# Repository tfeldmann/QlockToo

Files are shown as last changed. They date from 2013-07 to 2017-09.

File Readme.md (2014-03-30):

QlockToo
========
In this repository you find the software, firmware and hardware design for the
"QlockToo", an open-source remake of the QLOCKTWO by BIEGERT & FUNK.

It is built by four Westfälische Hochschule master mechatronics students.

Software
--------
The QlockToo Software Suite is written in PySide.

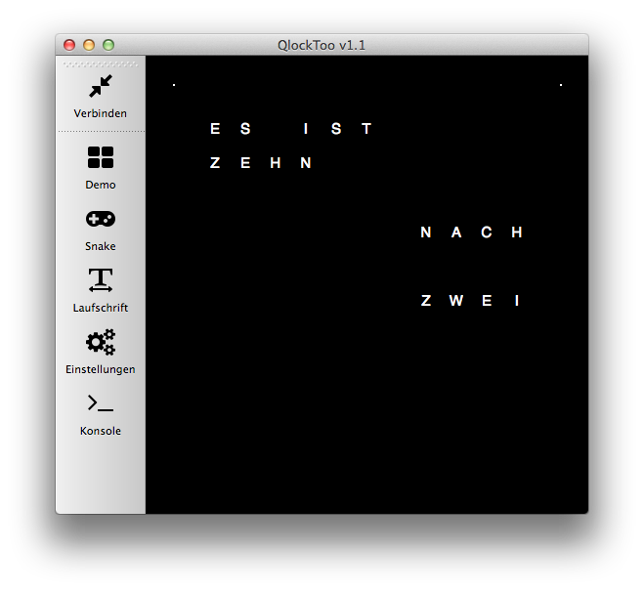
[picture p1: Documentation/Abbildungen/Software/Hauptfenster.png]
Software


Firmware
--------
We use an Arduino Micro as the central microcontroller.

License
-------
MIT-License - please refer to the License.txt in this repository.

Api
---
    @(get|set)brightness
        min                     int 0 - 255
        max                     int 0 - 255

    @(get|set)_nightmode
        brightness               int 0 - 255
        hour_start               int 0 - 23
        hour_end                 int 0 - 23
        minute_start             int 0 - 59
        minute_end               int 0 - 59

    @(get|set)kioskmode
        duration_words          int, minutes
        duration_seconds        int, minutes
        duration_temperature    int, minutes

    # matrix stream
    @m
        row     int 0 - 10
        values  bytearray

Errors
------

    !001 Unknown Command
    !002 Incorrect parameters

Authors
-------
- Thomas Feldmann
- Marlene Feldmann
- Manuel Fehmer
- Carsten Hußmann

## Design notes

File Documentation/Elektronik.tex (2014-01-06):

% !TEX root = QlockToo.tex
\begin{multicols}{2}
\section{Elektronik}
\label{sec:Elektronik}
Während sich Konstruktion und Basisfunktionen der Worduhr sehr eng am Original orientieren, ist die Umsetzung in der Elektronik komplett selbst entwickelt.

\textbf{LED-Matrix} Die LED-Matrix mit 10~x~11 Pixel wird von einem Mikrocontroller angesteuert. Dies geschieht zeilenweise im Multiplexing-Verfahren. Hierbei wird die erste Zeile von einem Transistor mit Spannung versorgt. Die 11 Pixel der Zeile werden über einen LED-Treiber simultan angesteuert. Nach einer Millisekunde wird die Zeile ausgeschaltet, es werden neue Daten in den LED-Treiber geschrieben und die nächste Zeile wird eingeschaltet.

\textbf{Arduino Micro} Als Mikrocontroller wird ein Arduino Micro Board mit dem Atmel Atmega 32U4 Controller verwendet. Der Einsatz eines Arduino Boards vereinfacht die Umsetzung einer seriellen Schnittstelle und verringert durch das bereits vielfach genutzte Board die Fehlerquellen im Layout. Durch die kleine Bauform und die sich aus den Features ergebenden Anforderungen (serielle Kommunikation, $I^{2}C$-Bus, externer Interrupt, 4x Digital Input, 2x Analogeingang und 10x Digital Output) fiel die Auswahl auf den Arduino Micro.

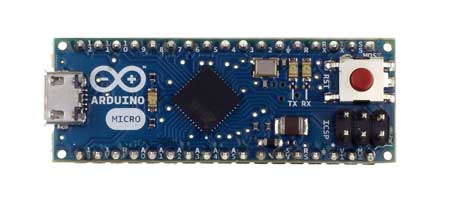
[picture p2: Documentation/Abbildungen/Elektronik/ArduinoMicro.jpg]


\textbf{LED-Treiber} Der TLC59116 LED-Treiber von Texas Instruments hat 16 PWM-Ausgänge mit 8Bit Auflösung - 256 Helligkeitsstufen - und eine Stromregelung, die es ermöglicht auf Vorwiderstände an den LED zu verzichten. Der IC wird über $I^{2}C$ angesteuert. Die Adresse kann hardwareseitig in den letzten 4Bit eingestellt werden und ist auf der Platine hart mit 0b1100 000[R/W] adressiert. Der LED-Treiber ist in der SMD TSSOP-28 Bauform.

\textbf{Transistoren} Die Zeilen werden mit IRF7416 P-FET-Transistoren geschaltet und mit $5V$ versorgt. Die Transistoren werden mit einem Pull-Up Widerstand am Gate beschaltet und mit einem invertierten Signal angesteuert (4~-~13). Die Transistoren haben S0-8 Gehäusebauform.

\textbf{Taster} Die vier Kurzhubtaster an der rechten Rahmenseite befinden sich auf einer eigenen Platine mit Verbindungskabel. Zur Entprellung befindet sich kurz vor den vier IO-Pins (A2~-~A5) des Controllers ein RC-Glied.

{
\centering
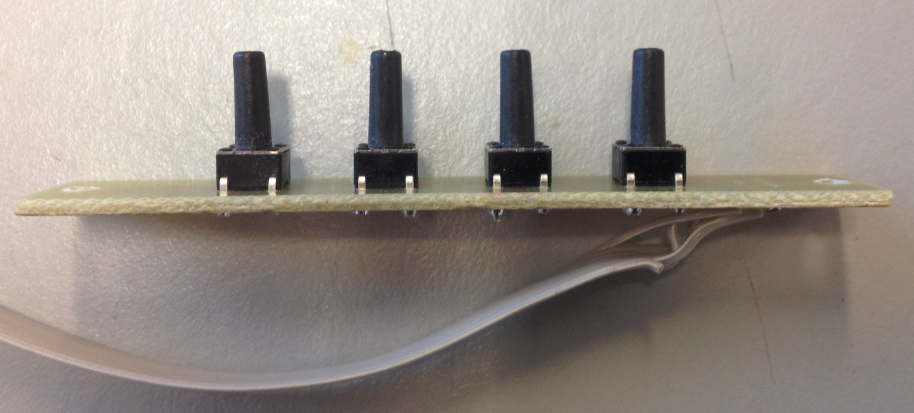
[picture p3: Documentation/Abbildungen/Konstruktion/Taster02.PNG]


}

{
\centering


}

Die vier Kurzhubtaster an der rechten Rahmenseite befinden sich auf einer eigenen Platine mit Verbindungskabel. Zur Entprellung befindet sich kurz vor den vier IO-Pins (A2~-~A5) des Controllers ein RC-Glied.

\textbf{Sensoren} Als Helligkeitssensor wird ein LDR und als Temperatursensor ein NTC verwendet, in beiden Fällen über Steckverbindung verbunden und einem Trimmpoti als Spannungsteiler an einem Analogeingang (A0~-~A1) des Mikrocontrollers. Der Helligkeitssensor befindet sich mittig oberhalb der Buchstabenmatrix hinter einem Loch in der Folie. Der Temperatursensor befindet sich seitlich am Rahmen um den Einfluss der möglichen Erwärmung der Elektronik auf den Sensor zu verringern. \newline

{
\centering
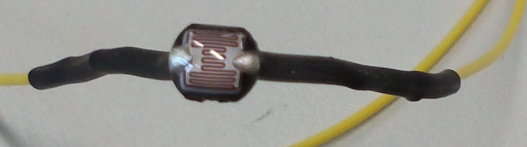
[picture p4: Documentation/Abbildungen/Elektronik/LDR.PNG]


}

{
\centering
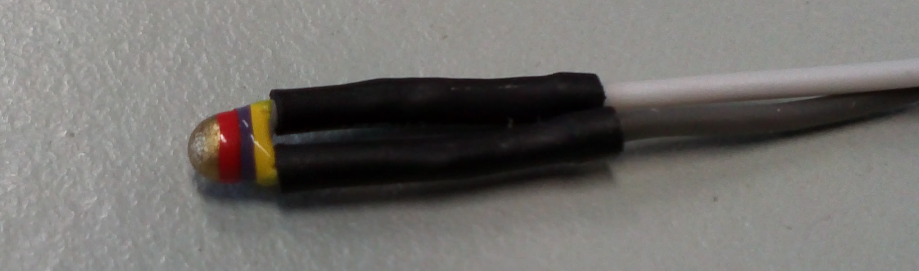
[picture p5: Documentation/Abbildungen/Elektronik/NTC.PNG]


}

\textbf{DCF77} Das DCF77-Modul empfängt das Mitteleuropäische Zeitsignal und verstärkt es. Um das Signal problemlos zu Empfangen wird hier ein interruptfähiger Eingang des Mikrocontrollers (1) verwendet. Durch regelmäßigen Empfang des DCF77 Zeitsignals ist die Genauigkeit des verbauten Quarz hinreichend genau.\newline

\textbf{Spannungsversorgung} Die Spannungsversorgung ist auf den Betrieb mit einem Gleichspannungsnetzteil (7~-~18$V$) ausgelegt und in die zwei Bereiche Elektronik und LED aufgeteilt. Der Bereich Elektronik wird von dem Spannungsregler auf dem Arduino Board versorgt. Die LEDs haben einen eigenen LM7805 Spannungsregler mit 1,5A Ausgangsstrom. An der Hohlsteckerbuchse am Rahmen kann alternativ ein Brückengleichrichter eingelötet werden, dieser verhindert die Verpolung des Netzteils und reduziert den Spannungsfall an den Spannungsreglern. Im Normalbetrieb benötigt die QlockToo 0,1A und 0,23A bei voller Helligkeit aller LED.

\textbf{Platinenlayout} Das Platinenlayout wurde mit dem PCB Design Tool CADSoft Eagle erstellt. Die Leiterbahnen des Top-Layers sind in Rot dargestellt und die Leiterbahnen, sowie die Massefläche, des Bottom-Layers sind in Blau dargestellt. Im oberen Bereich des Top-Layers befinden sich die 10 P-FET Transistoren mit  Pull-Up Widerständen. Rechts befindet sich der LED-Treiber mit dem Widerstand zur Stromregelung auf der Platinenunterseite. Links befindet sich der LM7805 und darunter der Spannungsanschluss. Mittig auf der Platine sind die Buchsenleisten für den Arduino Micro und das DCF77-Modul. Unten sind die Stiftleisten für den Stecker zum Tasterboard und die Spannungsteiler für NTC und LDR. Unterhalb des Arduino sind die RC-Glieder der Taster angeordnet. Desweiteren verläuft der $I^{2}C$-Bus mit den Pull-Up Widerständen auf dem Bottom-Layer durch die Massefläche. Auf Grund der eigenen Platinenfertigung und dem Verzicht von Durchkontaktierungen müssen einige Bauteile auf beiden Platinenseiten eingelötet werden und die nötigen Durchkontaktierungen mit Draht erstellt werden. Die Stiftleisten für den 10-poligen und den 16-poligen Stecker zur LED-Matrix werden stirnseitig angelötet.

Die Platine wird aus einer zweiseitigen Fotoplatine erstellt. Hierzu werden Top- und Bottom-Film auf der Fotoplatine ausgerichtet und die Platine drei Minuten mit UV-Licht belichtet. Im Entwicklerbad mit Natriumhydroxid wird der belichtete Fotolack abgewaschen. Die belichteten Stellen auf der Platine werden in einer Ätzanlage mit Eisentrichlorid entfernt. Je nach Güte des Ätzmittels verbleiben nach bereits zwei Minuten im Ätzbad nur noch die unter dem unbelichteten Fotolack liegenden Leiterbahnen. Im Nachgang wird die geätzte Platine nochmals vollständig belichtet, der Fotolack im Entwicklerbad abgewaschen und die Platine mit Kunststofflack beschichtet.

\textbf{Anschluss} Der Arduino Micro wird mit zwei Buchsenleisten auf die Platine aufgesteckt und bildet mit seinem ISP-Stecker das höchste Bauteil. Die Flachbandkabelstecker zur LED-Matrix werden mit der Nase nach oben aufgesteckt. Die Taster werden mit der Nase des sechspoligen Steckers in Richtung Matrix angeschlossen. Das DCF-Modul wird mit einem dreipoligen gewinkelten Stecker mit Winkel in Richtung Matrix angeschlossen. LDR und NTC besitzen keine Polarität, hierbei ist die Anschlussrichtung egal.
\end{multicols}

\begin{figure}[H]
    \centering
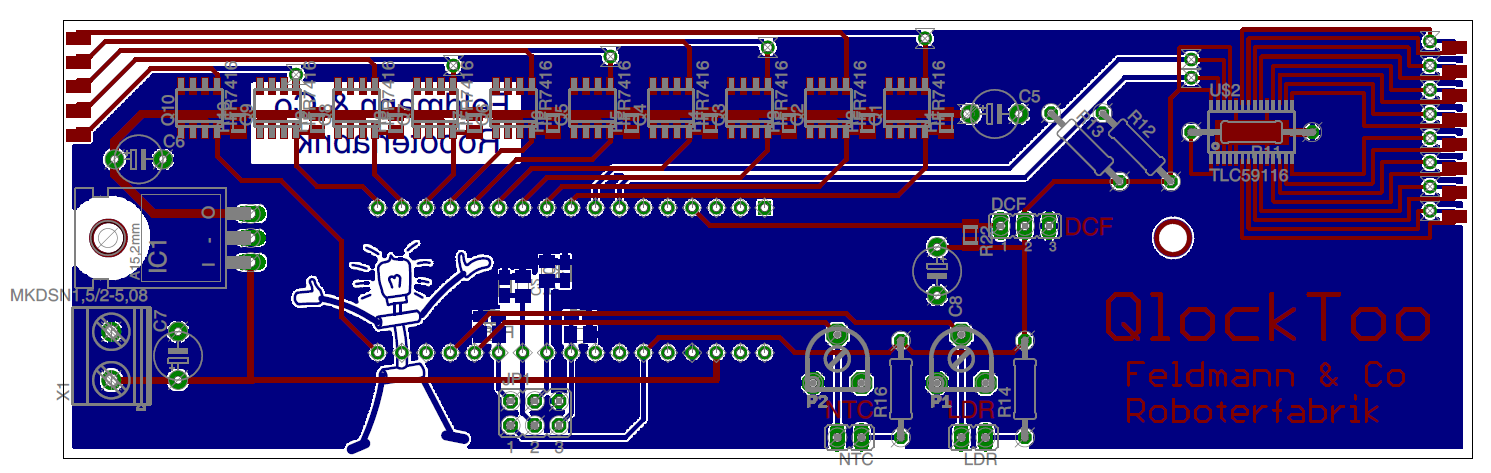
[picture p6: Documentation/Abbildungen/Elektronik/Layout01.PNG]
    
    \caption[]{Das Platinenlayout. Die Oberseite ist in Rot, die Unterseite mit zugehöriger Massefläche in Blau dargestellt.}
\end{figure}

\begin{figure}[H]
    \centering
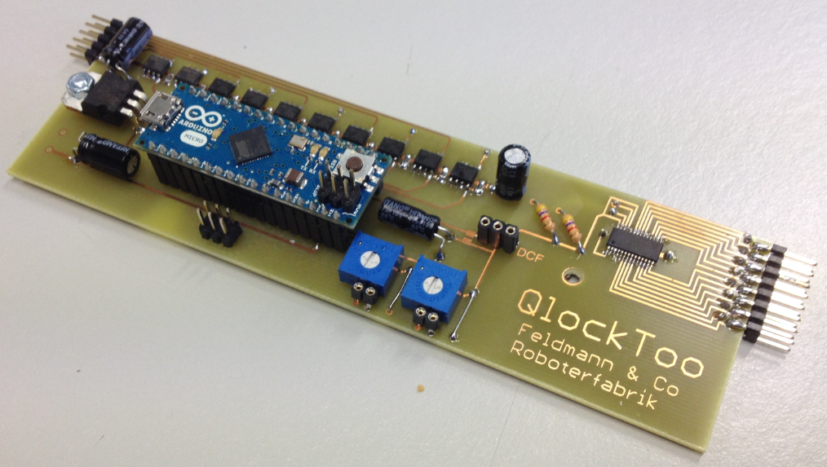
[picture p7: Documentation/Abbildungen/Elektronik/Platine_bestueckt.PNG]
    
    \caption[]{Die fertig bestückte Platine.}
\end{figure}

\begin{landscape}
	\begin{figure}[H]
		\centering
		
		\caption[Schaltplan]{Schaltplan}
		\label{fig:Schaltplan}

	\end{figure}
\end{landscape}

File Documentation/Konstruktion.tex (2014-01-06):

% !TEX root = QlockToo.tex

\section{Konstruktion und Produktion}
\label{sec:KonstruktionFertigung}

\begin{multicols}{2}
Um die Herstellungskosten möglichst gering zu halten wird die QlockToo als eine Kombination aus Kaufteilen und eigener Produktion ausgeführt. Ziel ist eine möglichst getreue Nachbildung der Original QLOCKTWO\textsuperscript{\textregistered} der Biegert~\&~Funk Manufacture GmbH \& Co. KG.

\textbf{Das Uhrgehäuse} Die Basis für das Uhrengehäuse bildet der IKEA-Bilderrahmen RIBBA in schwarz. Die Bilddarstellungsmaße von 50 x 50 cm eigenen sich gut, um die Buchstabenmatrix zur Geltung zu bringen.

{
\centering
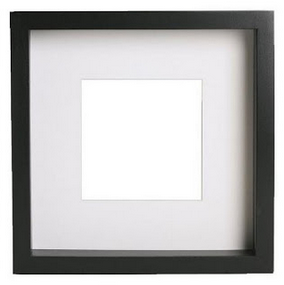
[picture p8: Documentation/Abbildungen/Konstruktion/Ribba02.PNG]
 %Bilderrahmen

}
In dem besonders tiefen Rahmen,  Tiefe~=~4,5~cm, kann die komplette LED-Matrix inklusive der Elektronik untergebracht werden. Es sind lediglich keine Modifikationen notwendig.
Zum Hinausführen des Stromkabels und zur Anbringung der Taster muss der Rahmen an den entsprechenden Stellen aufgebohrt werden.

{
\centering
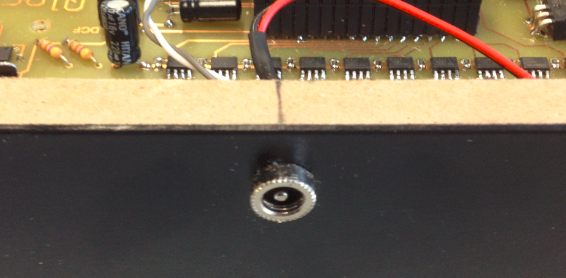
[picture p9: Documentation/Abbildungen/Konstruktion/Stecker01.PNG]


}

{
\centering


}

\textbf{Buchstabenfolie} Zur Darstellung der Zeit in Worten wird eine schwarze Folie mit einer negativen Buchstabenmatrix auf eine Plexiglasscheibe geklebt. Die Anordnung der Buchstaben entspricht der Original QLOCKTWO\textsuperscript{\textregistered}.

{
\centering
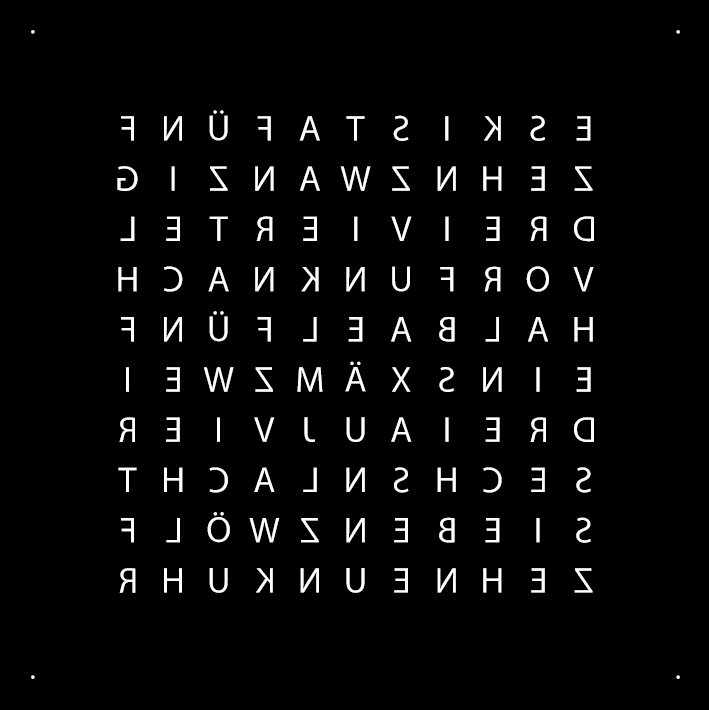
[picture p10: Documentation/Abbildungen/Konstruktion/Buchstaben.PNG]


}
Mit der gewählten Buchstabenmatrix ist die Uhr auf eine deutsche Anzeige festgelegt. Die Original QLOCKTWO\textsuperscript{\textregistered} CLASSIC beherrscht zwölf Sprachen. Durch Austauschen des Frontcovers kann die gewünschte Sprache eingestellt werden.

\textbf{LED-Matrix} Die LED-Matrix wird aus einer quadratischen MDF-Platte gefertigt. Abbildung ~\ref{fig:Spanplatte} zeigt die Fertigungs- bzw. Bearbeitungszeichnung der Spanplatte. Diese wird entsprechend der vorgegebenen Buchstabenmatrix -  10~x~11 Buchstaben - gebohrt und gesenkt, sodass die LEDs die kompletten Buchstaben ausleuchten können.

{
\centering
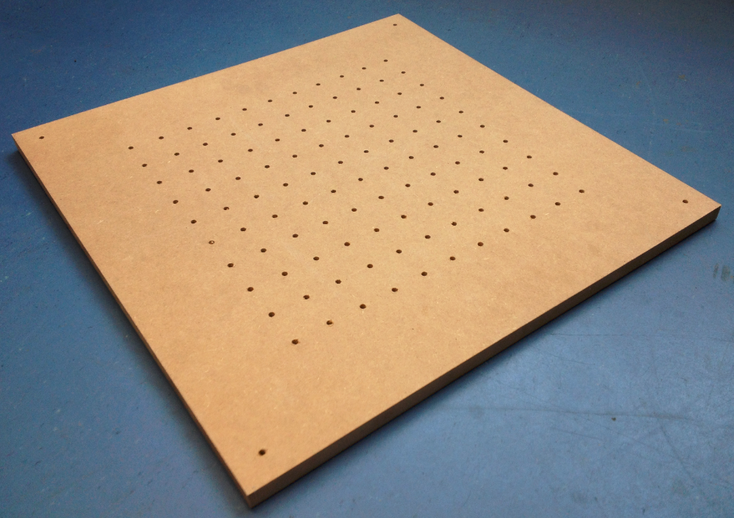
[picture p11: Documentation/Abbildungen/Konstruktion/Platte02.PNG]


}
Für den Lichtsensor und für die Minuten-LEDs werden weitere Löcher am oberen Rand und in den vier Ecken gebohrt. Zusätzlich wird ein Ausschnitt zur Aufnahme der Platine aus der Platte gefräst.

{
\centering
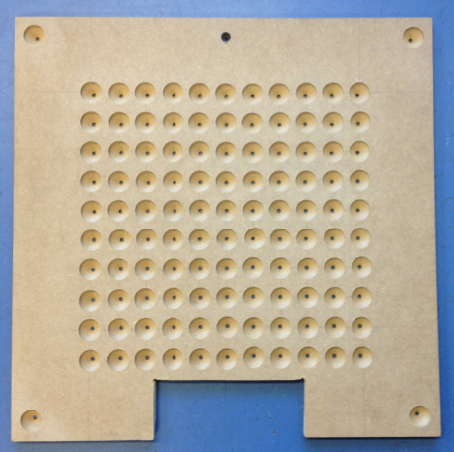
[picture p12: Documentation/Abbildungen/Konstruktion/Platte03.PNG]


}
Die LEDs werden entsprechend hinter den Löchern positioniert, verdrahtet und mit Heißkleber fixiert. Bei der Erstellung des LED-Gitters ist darauf zu achten, dass die LED-Beinchen, Anode und Kathode, immer in die selbe Richtung zeigen.

{
\centering
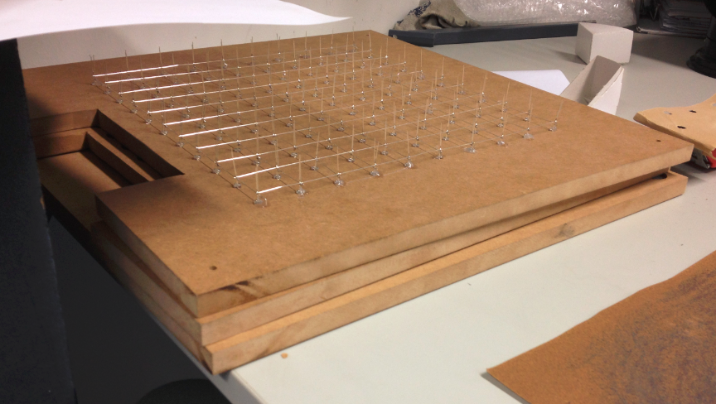
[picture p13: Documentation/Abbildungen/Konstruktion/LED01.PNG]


}
Die Verkabelung erfolgt möglichst direkt, einfach und übersichtlich mit Flachbandkabeln.

{
\centering
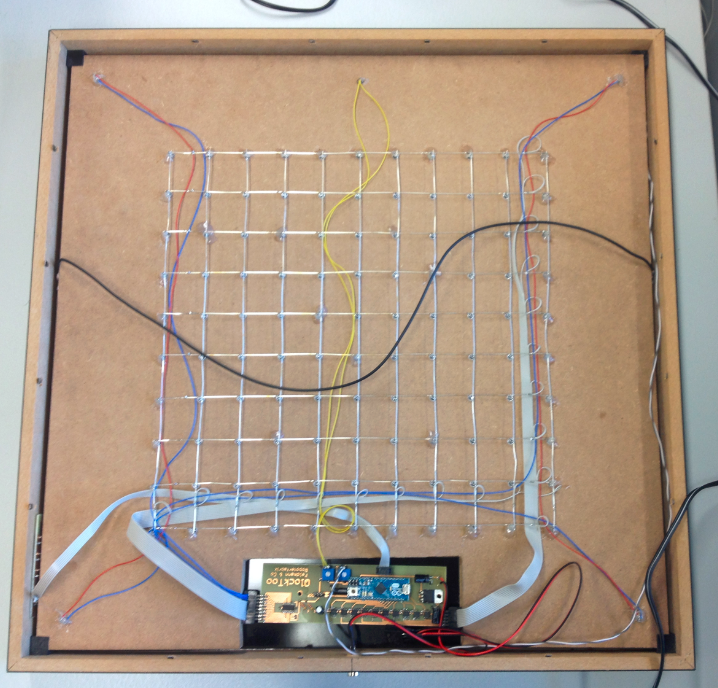
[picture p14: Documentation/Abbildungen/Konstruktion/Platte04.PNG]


}

\textbf{LEDs} Ohne eine zusätzliche Streuung kann man die LEDs hinter den jeweiligen Buchstaben deutlich erkennen. Eine vollständige Ausleuchtung ist nicht möglich.

{
\centering


}
Um eine möglichst breite Streuung des LED-Lichtes zu erzielen, wird hinter die Buchstabenfolie eine zweite Diffusorfolie  geklebt. Trotz der doppelten Folie ist die Streuung des Lichtes jedoch nicht ausreichend.

{
\centering
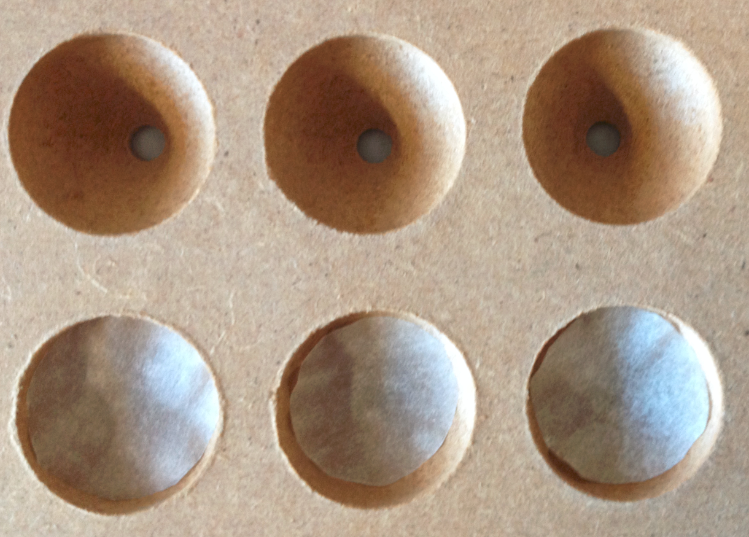
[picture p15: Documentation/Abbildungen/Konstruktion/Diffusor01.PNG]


}
Um diese zusätzlich zu erhöhen, wird ein Streuplättchen (D:~25~mm) aus transparentem Papier in die gesenkten Kegel geklebt.

{
\centering
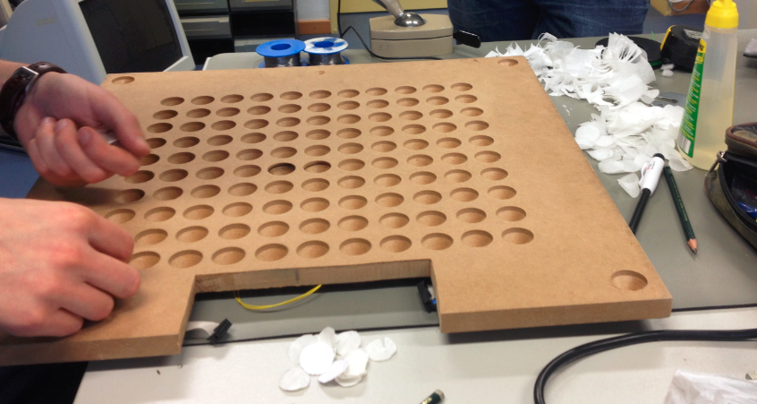
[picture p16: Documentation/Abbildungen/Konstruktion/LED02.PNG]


}

Zur Fixierung der LED -Matrix werden Winkel aus ABS gedruckt. Diese sorgen dafür, dass die MDF-Platte in Position gehalten wird. Schlussendlich wird noch ein Kabel an die MDF-Platte geschraubt, um die Uhr an die Wand zu hängen. Diese Aufhängung ermöglicht ein gerades Ausrichten an nur einem Punkt.

\end{multicols}

\begin{landscape}
	\begin{figure}
		\centering
		
		\caption[Spanplatte]{Fertigungszeichnung Spanplatte}
		\label{fig:Spanplatte}
	\end{figure}
\end{landscape}

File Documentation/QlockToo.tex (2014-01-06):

\input{LaTeX-Einstellungen}

\titlehead{
    \begin{tabular}{l p{9cm} c}
        & &  \\
        & & \textbf{Fachbereich Maschinenbau} \\

    \end{tabular}
    \vspace{1.5cm}}
\subject{Projektstudie}

\title{Entwicklung und Fertigung der elektronischen Design-Wanduhr \emph{QlockToo} mit Simulations-Software\vspace{1.5cm}}
\subtitle{Developing and building the electronic designer clock \emph{QlockToo} including simulation software\vspace{3cm}}

\author{
    \begin{tabular}{rl}
        Manuel Fehmer & 200923513 \\
        Thomas Feldmann & 200923381 \\
        Marlene Feldmann & 200825051 \\
        Carsten Hußmann & 200824460 \\
    \end{tabular}\vspace{0.3cm}
}

\begin{document}
\begin{titlepage}
\maketitle
\pagenumbering{gobble}
\end{titlepage}
\tableofcontents
\pagenumbering{arabic}
\newpage

\include{Einleitung}
\include{Elektronik}
\include{Konstruktion}
\include{Software}
\include{Firmware}

\include{Literatur}

\end{document}

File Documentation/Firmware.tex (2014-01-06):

% !TEX root = QlockToo.tex

\section{Firmware}
\label{sec:Firmware}

\begin{figure}
    
    \caption{Für die Anzeige der Zeit in Sätzen wird die dargestellte Logiktabelle für die deutsche Sprache in der Firmware hinterlegt. \emph{Stunde} und \emph{Stunde + 1} sind Platzhalter für die aktuelle und die nächste Stunde.}
    \label{fig:Logik}
\end{figure}

Die Firmware der QlockToo ist in \emph{C} geschrieben und nutzt Funktionen des Arduino-Cores.
Im Folgenden werden die einzelnen Module der Firmware kurz erläutert.

\begin{multicols}{2}
\textbf{Firmware}
Die Hauptdatei der Firmware enthält den Einstiegspunkt in das Programm und initialisiert alle Module. Hier wird der Haupttimer (1kHz) gestartet, der Displayanzeige und Steuerungsfunktionen übernimmt.

\textbf{Display}
Im Display-Modul wird die Verbindung mit dem I2C-LED-Treiber hergestellt und die Ports für die Ansteuerung der Leistungstransistoren werden konfiguriert.

In der Display-Update-Routine findet das eigentliche Multiplexing statt. Es wird jeweils die nächste LED-Reihe eingeschaltet und die darzustellenden Spalten über die I2C-Schnittstelle an den LED-Treiber gesendet.
Diese Funktion ist besonders zeitkritisch, da ineffiziente Programmierung hier sofort zu einem flimmernden Bild führt.
Die QlockToo baut das Bild 100 mal pro Sekunde komplett auf (Multiplexing mit 1kHz über zehn Reihen), mit bloßen Auge ist daher kein Flimmern zu erkennen.

\textbf{Controller}
Im Controller-Modul befindet sich ein Zustandsautomat, welcher den Betriebsmodus (Zeitanzeige, Temperaturanzeige, usw.) verwaltet.
Der Betriebsmodus der Uhr kann über die Taster eingestellt werden. Das dazu notwendige Abfragen der Taster findet ebenfalls in diesem Modul statt.

\textbf{Timewords}
In diesem Modul ist die in Abbildung~\ref{fig:Logik} dargestellte Logiktabelle implementiert.
Welche LEDs für die gewählten Wörter und Stunden zu beleuchten sind, wird für jedes Wort in Form eines Integers für die Reihe und einer Bitmaske für die Spalten definiert.

\textbf{Api}
Die QlockToo kommuniziert per USB über das UART-Protokoll bei 115200 baud mit der Software.
Zum Parsen der empfangenen Befehle wird auf Seite der Firmware die Library \emph{SerialCommand}\footnote{https://github.com/kroimon/Arduino-SerialCommand} eingesetzt.

\textbf{Brightness}
Das Modul Brightness beinhaltet die Steuerung der Helligkeit der QlockToo. Neben dem Automatikmodus, welcher die Helligkeit der Abhängigkeit von den gemessenen Werten des Helligkeitssensors steuert, besteht die Möglichkeit einer manuellen Steuerung. Dabei stehen verschiedene Abstufungen zur Verfügung.

\textbf{DCF77}
In diesem Modul ist der Parser für das DCF77 Signal implementiert. Das DCF77-Signal ist zeitkritisch und wird daher in einem dedizierten Interrupt bearbeitet.
Sobald alle notwendigen Daten vorhanden sind -- was mindestens eine Minute dauert -- und der Paritätscheck erfolgreich ist, wird die globale interne Uhrzeit eingestellt.

\textbf{Matrix}
Im Modul \emph{Matrix} sind Funktionen zu Manipulation der Anzeigematrix zusammengefasst. Diese reichen vom Leeren und Füllen der Matrix hin zum Anzeigen von Zahlen und Buchstaben. Die Schriftarten sind in der Datei \emph{font.h} hinterlegt.

\textbf{Thermo}
Dieses Modul enthält die Umrechnung der gemessenen Spannung am Thermistor in eine Temperatur in Celsius.
Dazu kommen Anzeigefunktionen, die die Temperatur auf dem Display ausgeben.
Für die Anzeige der Temperatur wird eine kleinere Schriftart (3x5) genutzt als für die Anzeige der Sekunden (5x7), da noch das Gradzeichen angezeigt wird.

\textbf{Time}
Die QlockToo nutzt den internen 16-Bit Timer1 dazu, die Zeit einzuhalten.
Der Timer wird mit einem Prescaler von 256 Overflow-Betrieb genutzt und mit dem Wert 3036 vorgeladen.
Dadurch feuert der Timer exakt sekündlich und zählt Minuten und Stunden hoch.

\subsection*{Tastenbelegung}
Neben der Darstellung der Uhrzeit in Worten verfügt die \emph{QlockToo} über zahlreiche weitere Funktionen.
Während einige Funktionen und Demonstrationsmuster nur über die Software gestreamt werden können\footnote{Die Modi, welche über die Software auf die Uhr gestreamt werden können, sind im Kapitel~\ref{sec:Software} beschrieben.
Zur Übertragung muss die Uhr über die USB-Schnittstelle direkt an einen PC angeschlossen sein.}, so sind die wichtigsten Funktionen bereits in die Uhr integriert.
Sie können über vier Taster, welche sich seitlich am Rahmen befinden, ausgewählt werden.

Die Tastenbelegung ist dabei wie folgt:
\begin{description}
    \item[Taster 1:] Anzeige der Uhrzeit in Worten.
    \item[Taster 2:] Anzeige der Sekunden.
    \item[Taster 3:] Anzeige der Raumtemperatur in $^\circ$C.
    \item[Taster 4:] Ein kurzer Druck auf den Taster 4 wechselt zwischen den vordefinierten Helligkeitsstufen.
    Nach einem langen Druck (> 1 Sekunde) befindet sich die Uhr im automatischen Helligkeitsmodus.
    Die Displayhelligkeit ist hier abhängig vom Umgebungslicht.
    \item[Taster 1 \& 2:] Wird der erste Taster gedrückt gehalten, können durch mehrmaliges Tippen auf den zweiten Taster weitere Demonstrationsmuster durchgeschaltet werden.
    So ist es beispielsweise möglich, alle LEDs einzuschalten oder den aus dem Kapitel~\ref{sec:Software} bekannten Matrix-Effekt zu aktivieren.
    \item[Taster 1-3 lang:] Werden die oberen drei Taster länger als eine Sekunde gehalten, schaltet die Uhr in den DCF-Empfangsmodus.
    Dabei ist das Multiplexing deaktiviert, um mögliche Empfangsstörungen zu minimieren. Lediglich das Wort \emph{FUNK} wird in der Mitte der Uhr angezeigt.
    Nach Empfang des vollständigen Zeitsignals schaltet die Uhr automatisch in den Modus \emph{Zeitwörter}.
\end{description}

\end{multicols}

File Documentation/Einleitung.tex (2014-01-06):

% !TEX root = QlockToo.tex
% Kapitelvorlage

\section{Einleitung}
\label{sec:Einleitung}

\begin{figure}[t]
    \centering
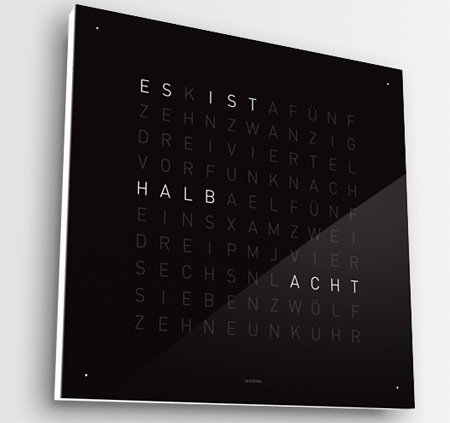
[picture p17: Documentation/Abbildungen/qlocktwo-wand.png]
    
    \caption[QlockTwo]{QLOCKTWO CLASSIC}
    \label{fig:QlockTwo}
\end{figure}
%
 \begin{multicols}{2}
 In der heutigen Zeit steht neben der Funktionalität vieler Dinge ihr Design im Vordergrund. Bestes Beispiel ist die QLOCKTWO\textsuperscript{\textregistered} der Biegert~\&~Funk Manufacture GmbH \& Co. KG. Abbildung~\ref{fig:QlockTwo} zeigt die QLOCKTWO CLASSIC\footnote{\cite{Bie 13}} als Wand- oder Standuhr. %Die QLOCKTWO® ist ein international eingetragenes Markenzeichen, welches zudem durch internationale Patente und Designpatente geschützt ist.
 \emph{Zeit in zeitlosem Design}, so bewirbt die Designmanufaktur die einzigartige Uhr.
 Inspiriert durch diese außergewöhnliche Darstellung der Zeit in geschriebenen Worten, entsteht das Entwicklungs- und Fertigungskonzept einer elektronischen Wanduhr mit einer LED-Matrix. \emph{We can build a QLOCK, TOO.}
 \end{multicols}
 %
 \begin{figure}[h]
    \centering
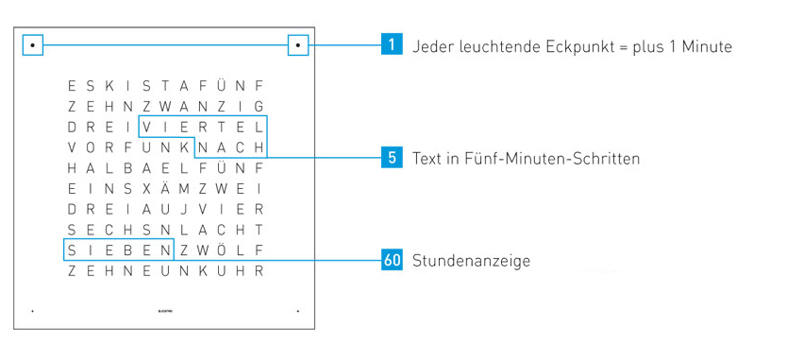
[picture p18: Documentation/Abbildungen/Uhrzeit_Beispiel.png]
    
    \caption[Uhrzeit_Bspl]{Beispiel: 7 Uhr 17}
    \label{fig:Uhrzeit_Bspl}
\end{figure}
 %
\begin{figure}[t]
    \centering
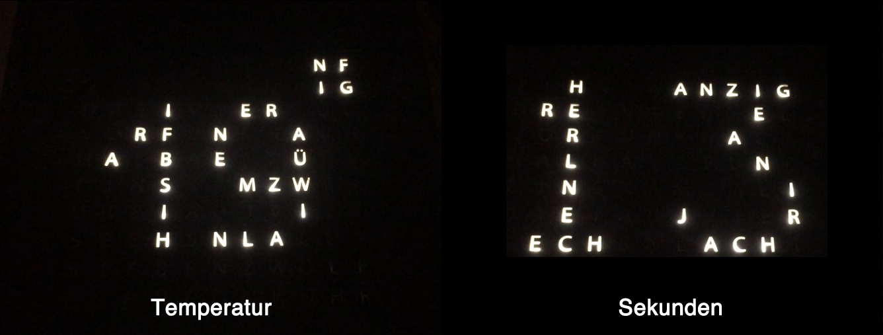
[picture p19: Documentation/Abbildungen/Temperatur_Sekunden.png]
    
    \caption[]{Darstellung der Temperatur und Sekunden}
    \label{fig:Sekunden}
\end{figure}
%
\begin{multicols}{2}
Die Zeitanzeige erfolgt auf einer Buchstabenmatrix in Fünf-Minuten-Schritten, siehe Abbildung~\ref{fig:Uhrzeit_Bspl}. Die Worte werden durch Ausleuchten einer Buchstabenfolie auf einer Plexiglasscheibe durch LEDs abgebildet. Durch vier zusätzliche Leuchtpunkte in den Ecken der Uhr werden die Minuten zwischen den Intervallen angezeigt. Abbildung~\ref{fig:Sekunden} zeigt die Darstellung der Sekunden. Auf der kompletten Matrix kann ebenfalls die Raumtemperatur angezeigt werden. Die Umstellung erfolgt sowie die Auswahl weiterer Funktionen über seitliche Taster. Vor der Konzeption der Wortuhr steht die Programmierung einer Desktop-Software, welche den Testprozess der Algorithmen beschleunigt. Die Software ermöglicht zudem die Darstellung weiterer Unterprogramme. Auch ein Simulator ist implementiert.

Bei der Konstruktion sowie der Fertigung des Uhrgehäuses werden Kaufteile mit Eigenproduktionen kombiniert, um dem äußeren Erscheinungsbild des Originals möglichst nah zu kommen und die Kosten gering zu halten. Die Entwicklung eines Elektronikkonzepts ist  weiterer fundamentaler Bestandteil der Projektstudie.
\end{multicols}

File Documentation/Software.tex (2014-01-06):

% !TEX root = QlockToo.tex
\section{Software}
\label{sec:Software}

\begin{figure}[t!]
    \centering
    
    \caption[QlockToo-Manager]{Der QlockToo-Manager}
    \label{fig:Manager}
\end{figure}

\begin{multicols}{2}
Im ersten Projektschritt zur Entwicklung der Uhr wird eine Desktop-Software, der QlockToo-Manager, programmiert, welche den Testprozess der Algorithmen deutlich beschleunigt. Mit weiterem Projektfortschritt wächst auch der Programmumfang. Durch stetige Weiterentwicklung kommen zahlreiche Funktionen hinzu, welche im folgenden dargestellt sind:

\begin{itemize}
    \item Die Software enthält einen Simulator. Dieser stellt alle Muster und Algorithmen direkt ohne Anschluss an die Hardware dar.
    \item Zu Testzwecken sind verschiedene Demonstrationsmuster implementiert.
    \item Mit Hilfe einer Laufschrift können frei wählbare Texte angezeigt werden.
    \item Das Handyspiel Snake kann auf dem Uhrenschirm gespielt werden. Die Steuerung erfolgt über die Pfeiltasten am Computer.
    \item Über eine USB-Schnittstelle fungiert die QlockToo als Display der Software. Das notwendige Streaming-Protokoll wird eigens für diese Anwendung entwickelt.
    \item Zur Einstellung der QlockToo über den Computer ist ein Einstellungsdialog implementiert.
\end{itemize}

\subsection*{Aufbau}
Um eine Lauffähigkeit auf allen gängigen Plattformen (Windows / Mac OS X / Linux) zu realisieren wird die Programmiersprache Python verwendet. Weiterer Vorteil ist die hohe Entwicklungsgeschwindigkeit.
Das aus der C++ - Welt bekannte Framework Qt wird über die von Digia bereitgestellten PySide-Bindings als GUI-Framework genutzt. Die Software baut somit ausschließlich auf freier Open-Source Software auf.

\subsection*{Simulator}
Der QlockToo-Manager zeigt nach dem Start den Simulator. Seitlich wird eine Menüleiste zum Starten der Unterprogramme dargestellt.
Solange kein Unterprogramm ausgewählt ist, wird standardmäßig das Programm \emph{Timewords}, welches für die Anzeige der Zeit in Worten zuständig ist, angezeigt. Der QlockToo-Manager bedient sich dazu der momentanen Systemzeit.
Die Unterprogramme sind jeweils einzelne, voneinander unabhängige Python-Module. Eine Erweiterung ist somit jederzeit möglich.
Der Simulator besitzt die gleiche API wie die Hardware. Die Ausgabe der Programme kann somit ohne Anpassungen auf die Hardware gestreamt oder im Simulator angezeigt werden. Auch eine parallele Darstellung ist möglich.
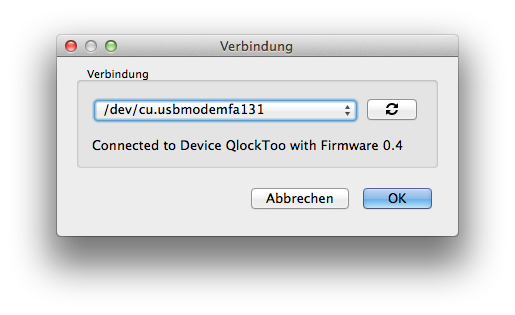
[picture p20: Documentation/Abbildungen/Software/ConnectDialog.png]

Im Entwicklungsmodus ist eine Konsole integriert, mit der direkt Befehle an die API der QlockToo gesendet werden können. Kommandos und Rückgabewerte werden zur einfacheren optischen Erfassung farblich hervorgehoben.
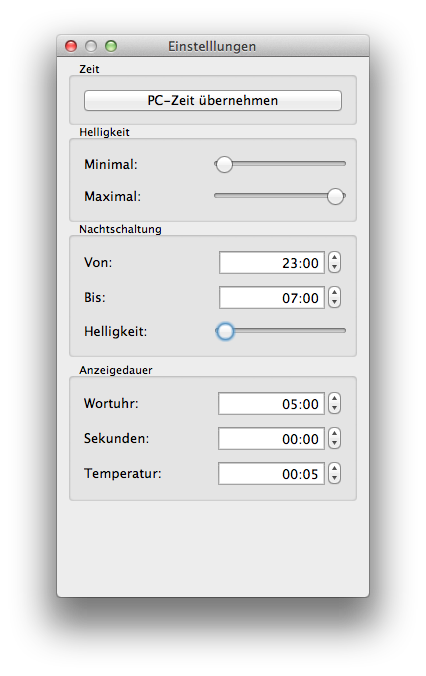
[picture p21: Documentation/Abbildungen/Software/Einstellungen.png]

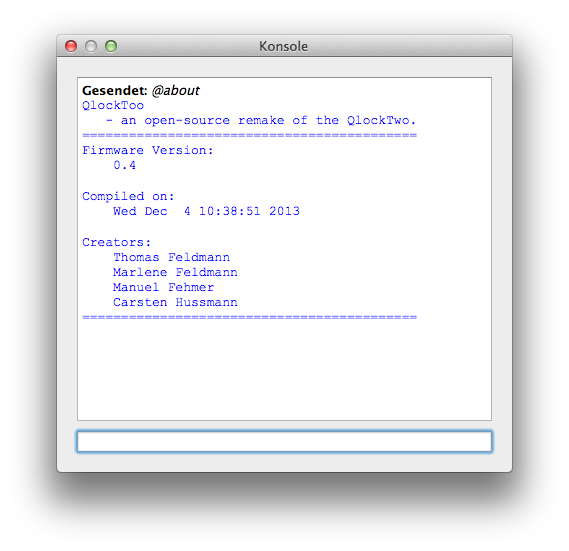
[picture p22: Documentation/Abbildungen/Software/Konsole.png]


\subsubsection*{Demonstrationsmuster}
Der zweite Punkt in der Menüleiste sind die Demonstrationsmuster.
Zur besseren Sichtbarkeit sind die Muster invertiert dargestellt.
Folgende Demonstrationen stehen zur Verfügung:
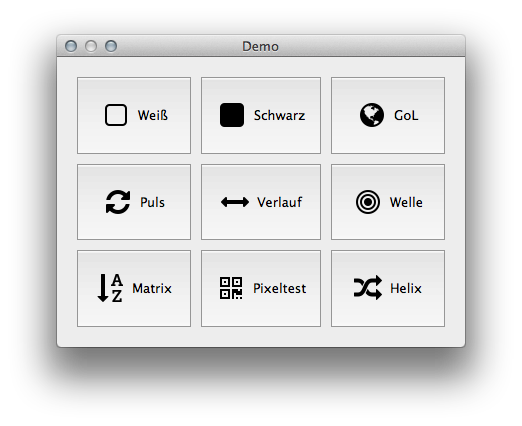
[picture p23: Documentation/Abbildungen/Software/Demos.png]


\textbf{Puls}
Alle LEDs wechseln sanft zwischen minimaler und maximaler Helligkeit.

\textbf{Pixeltest}
Alle Pixel bzw. Buchstaben werden einzeln nacheinander beleuchtet. Diese Demo dient hauptsächlich der Überprüfung der Verkabelung.

\textbf{Verlauf}
Ein Helligkeitsverlauf bewegt sich sinusförmig von links nach rechts und zurück.
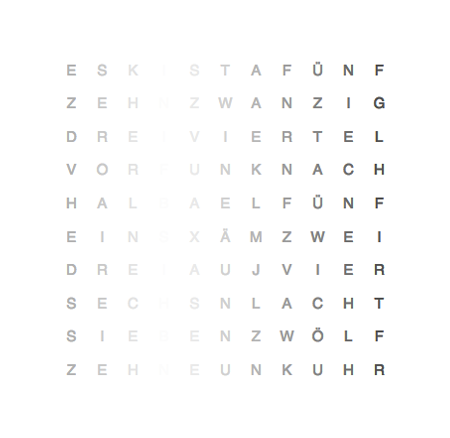
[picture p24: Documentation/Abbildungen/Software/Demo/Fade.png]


\textbf{Welle}
Diese Demo zeigt ein pulsierendes Wellenbild, dessen Zentrum mit der Zeit langsam über den Bildschirm wandert.
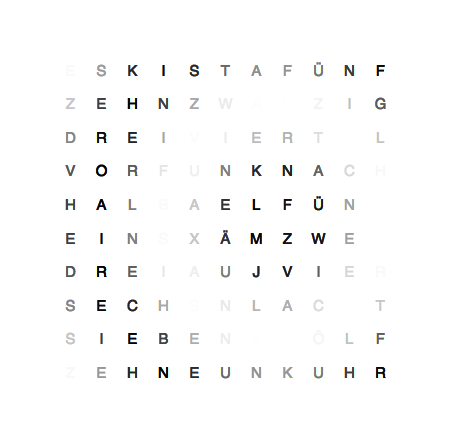
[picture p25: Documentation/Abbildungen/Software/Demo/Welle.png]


\textbf{Helix}
Die Helix-Darstellung zeigt die zweidimensionale Projektion einer dreidimensionalen Spirale. Die z-Achse wird dabei über unterschiedliche Helligkeitswerte visualisiert. Bedingt durch die Berechnung der Funktionswerte für diskrete Buchstaben auf der Uhr und die geringe Pixelanzahl (110) wirkt die Demonstration zunächst sehr dünn und zerstückelt. Durch die Implementierung eines Gauss-Tiefpasses, wird der gewünschte Anti-Alias-Effekt erzielt. Der 3D~Effekt der Darstellung ist somit sehr viel deutlicher.



\textbf{Game Of Life}
Darstellung von Conways Game of Life\footnote{[Con 13]}, anhand toter (schwarz) und lebender (weiß) Zellen.
Grundlage sind die vier folgenden Regeln, die bei jeder Iteration abgefragt werden:
\begin{itemize}
    \item Eine tote Zelle mit genau drei lebenden Nachbarn wird in der Folgegeneration neu geboren.
    \item Lebende Zellen mit weniger als zwei lebenden Nachbarn sterben in der Folgegeneration an Einsamkeit.
    \item Eine lebende Zelle mit zwei oder drei lebenden Nachbarn bleibt in der Folgegeneration lebend.
    \item Lebende Zellen mit mehr als drei lebenden Nachbarn sterben in der Folgegeneration an Überbevölkerung.
\end{itemize}

\textbf{Matrix}
Der berühmte Animationseffekt aus dem Film \emph{Matrix} bietet sich aufgrund des Designs der QlockToo besonders an.


\textbf{Laufschrift}
Der vierte Punkt in der Menüleiste ist die Laufschrift. Über ein Fenster kann ein beliebiger Text eingegeben werden, welcher auf der Uhr als Laufschrift abgespielt werden soll. Zum Abspielen muss ein Häkchen im entsprechenden Kontrollkästchen gesetzt werden.
Ohne das Häkchen werden bei der Eingabe die einzelnen Buchstaben angezeigt. Über den Drehregler können die Laufrichtung und die Geschwindigkeit variiert werden.


\end{multicols}

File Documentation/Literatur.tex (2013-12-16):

% !TEX root = Frontkollisionsassistenzsysteme.tex
\begin{thebibliography}{sotief}
\bibliographystyle{dinat} % DIN-Stil des Literaturverzeichnisses

\bibitem[Bie 13]{Bie 13}
Biegert, Marco; Funk, Andreas:
\newblock {\em B~\&~F Manufacture Verwaltungs-GmbH} %Register-Nr.:~HRB~729102,}
\newblock \\URL: http://www.qlocktwo.com/news.php?lang=de (Stand: 02.12.2013)

\bibitem[Con 13]{Con 13}
Conway, John Horton:
\newblock {\em Conways Spiel des Lebens}
\newblock \\URL: http://de.wikipedia.org/wiki/Conways\_Spiel\_des\_Lebens (Stand: 02.12.2013)

\end{thebibliography}

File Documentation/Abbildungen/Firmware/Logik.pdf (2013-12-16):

Minute | “ES IST” | “FÜNF” | “ZEHN” | “VIERTEL” | “ZWANZIG” | “VOR” | “NACH” | “HALB” | Stunde | Stunde + 1 | “UHR”
0 | 1 | 0 | 0 | 0 | 0 | 0 | 0 | 0 | 1 | 0 | 1
5 | 1 | 1 | 0 | 0 | 0 | 0 | 1 | 0 | 1 | 0 | 0
10 | 1 | 0 | 1 | 0 | 0 | 0 | 1 | 0 | 1 | 0 | 0
15 | 1 | 0 | 0 | 1 | 0 | 0 | 1 | 0 | 1 | 0 | 0
20 | 1 | 0 | 0 | 0 | 1 | 0 | 1 | 0 | 1 | 0 | 0
25 | 1 | 1 | 0 | 0 | 0 | 1 | 0 | 1 | 0 | 1 | 0
30 | 1 | 0 | 0 | 0 | 0 | 0 | 0 | 1 | 0 | 1 | 0
35 | 1 | 1 | 0 | 0 | 0 | 0 | 1 | 1 | 0 | 1 | 0
40 | 1 | 0 | 0 | 0 | 1 | 1 | 0 | 0 | 0 | 1 | 0
45 | 1 | 0 | 0 | 1 | 0 | 1 | 0 | 0 | 0 | 1 | 0
50 | 1 | 0 | 1 | 0 | 0 | 1 | 0 | 0 | 0 | 1 | 0
55 | 1 | 1 | 0 | 0 | 0 | 1 | 0 | 0 | 0 | 1 | 0

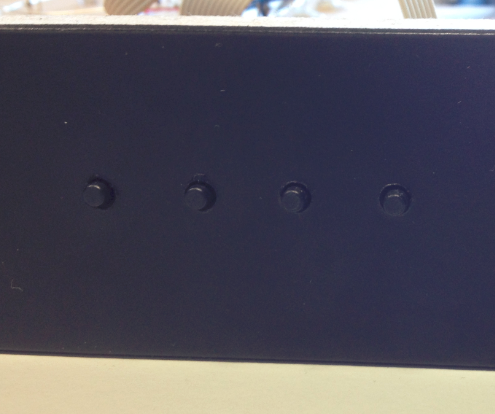
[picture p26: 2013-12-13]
Documentation/Abbildungen/Konstruktion/Taster01.PNG

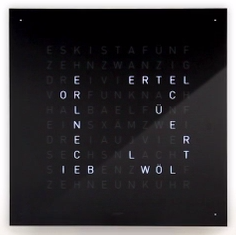
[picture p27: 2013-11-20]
Documentation/Abbildungen/Sekunden.PNG

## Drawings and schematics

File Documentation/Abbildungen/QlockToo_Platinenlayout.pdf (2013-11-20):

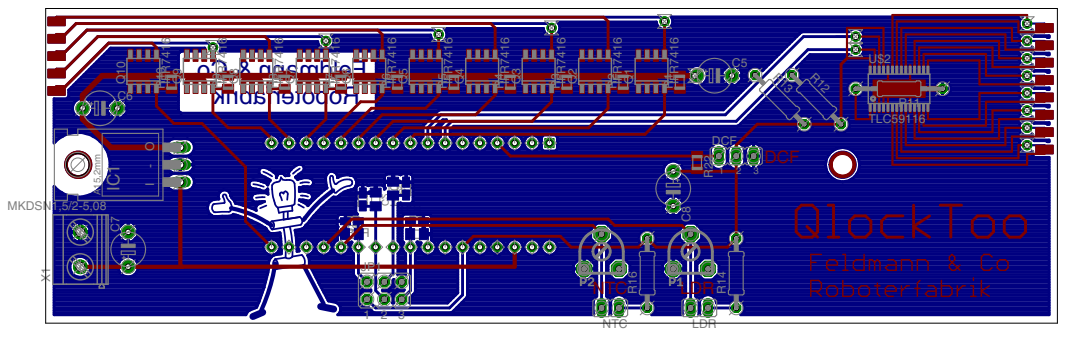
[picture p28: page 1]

81R R19R20 12R 1C C2C3 4C oC & nna mdl eF kir bafr et oboR DCF NTC LDR 1 2 3 A15,2mm 1 2 3 - I O U$2 Q1 Q2 Q3 Q4 Q5 Q6 Q7 Q8 Q9 Q10 R1R2R3R4R5R6R7R8R9R10 R11 R12 R13 DCF X1 NTC LDR R14 R16P2 P1 C5 C6C7C8 IC1R22 JP1 TLC59116 IFR7416 IFR7416 IFR7416 IFR7416 IFR7416 IFR7416 IFR7416 IFR7416 IFR7416 IFR7416 MKDSN1,5/2-5,08

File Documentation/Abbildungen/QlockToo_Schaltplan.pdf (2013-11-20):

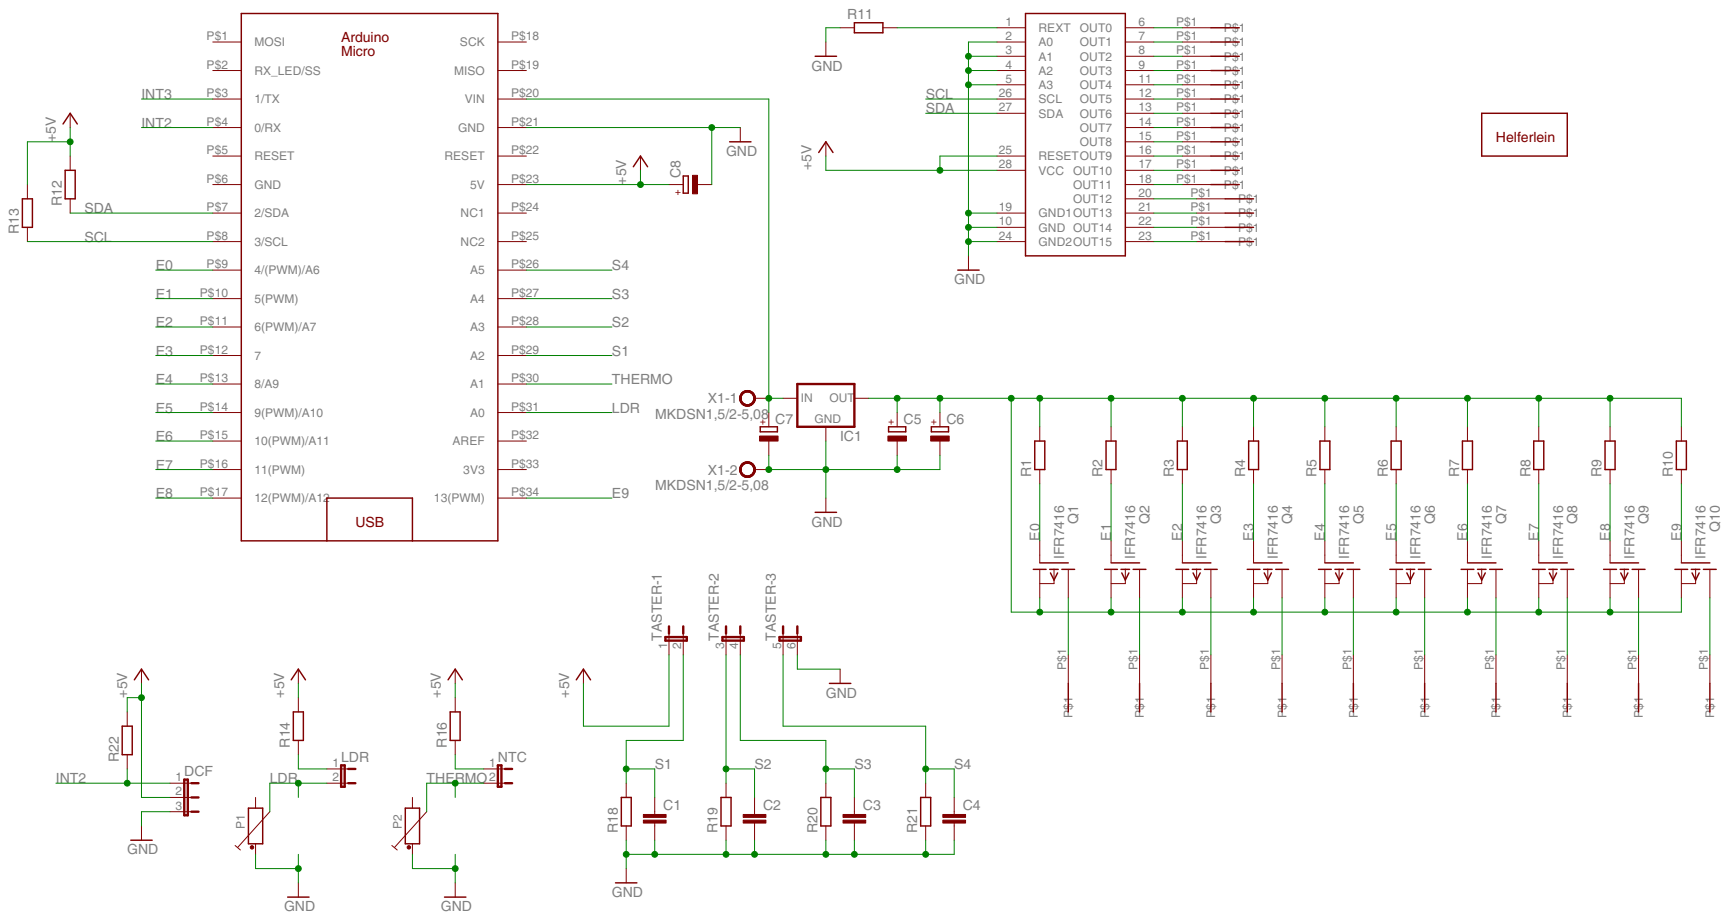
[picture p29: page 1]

IFR7416 IFR7416 IFR7416 IFR7416 IFR7416 IFR7416 IFR7416 IFR7416 IFR7416 IFR7416 GND GND +5V GND +5V +5V GND MKDSN1,5/2-5,08 MKDSN1,5/2-5,08 +5V +5V GND GND GND +5V GND +5V GND MOSI P$1 RX_LED/SS P$2 1/TX P$3 0/RX P$4 RESET P$5 GND P$6 2/SDA P$7 3/SCL P$8 4/(PWM)/A6 P$9 5(PWM) P$10 6(PWM)/A7 P$11 7 P$12 8/A9 P$13 9(PWM)/A10 P$14 10(PWM)/A11 P$15 11(PWM) P$16 12(PWM)/A12 P$17 SCK P$18 MISO P$19 VIN P$20 GND P$21 RESET P$22 5V P$23 NC1 P$24 NC2 P$25 A5 P$26 A4 P$27 A3 P$28 A2 P$29 A1 P$30 A0 P$31 AREF P$32 3V3 P$33 13(PWM) P$34 REXT 1 A0 2 A1 3 A2 4 A3 5 OUT0 6 OUT1 7 OUT2 8 OUT3 9 GND 10 OUT4 11 OUT5 12 OUT6 13 OUT7 14 VCC 28 SDA 27 SCL 26 RESET 25 GND2 24 OUT15 23 OUT14 22 OUT13 21 OUT12 20 GND1 19 OUT11 18 OUT10 17 OUT9 16 OUT8 15 Q1 Q2 Q3 Q4 Q5 Q6 Q7 Q8 Q9 Q10 R1R2R3R4R5R6R7R8R9R10 R11 R12 R13 P$1 P$1 P$1 P$1 P$1 P$1 P$1 P$1 P$1 P$1 P$1 P$1 P$1 P$1 P$1 P$1 P$1 P$1 P$1 P$1 P$1 P$1 P$1 P$1 P$1 P$1 P$1 P$1 P$1 P$1 P$1 P$1 P$1 P$1 P$1 P$1 P$1 P$1 P$1 P$1 P$1 P$1 P$1 P$1 P$1 P$1 P$1 P$1 P$1 P$1 P$1 P$1 DCF 123 X1-1 X1-2 LDR 12 NTC 12 R14 R16 P1P2 R18 R19 R20 R21C1 C2 C3 C4 C7 C5 C6 C8 IC1 GND IN OUT R22 TASTER-1 12TASTER-2 34TASTER-3 56 E0 E0 E1 E1 E2 E2 E3 E3 E4 E4 E5 E5 E6 E6 E7 E7 E8 E8 E9 E9 SDA SDA SCL SCL LDR LDR INT3 INT2 INT2 THERMO THERMOS1 S1 S2 S2 S3 S3 S4 S4 USB Arduino Micro Helferlein +++ +

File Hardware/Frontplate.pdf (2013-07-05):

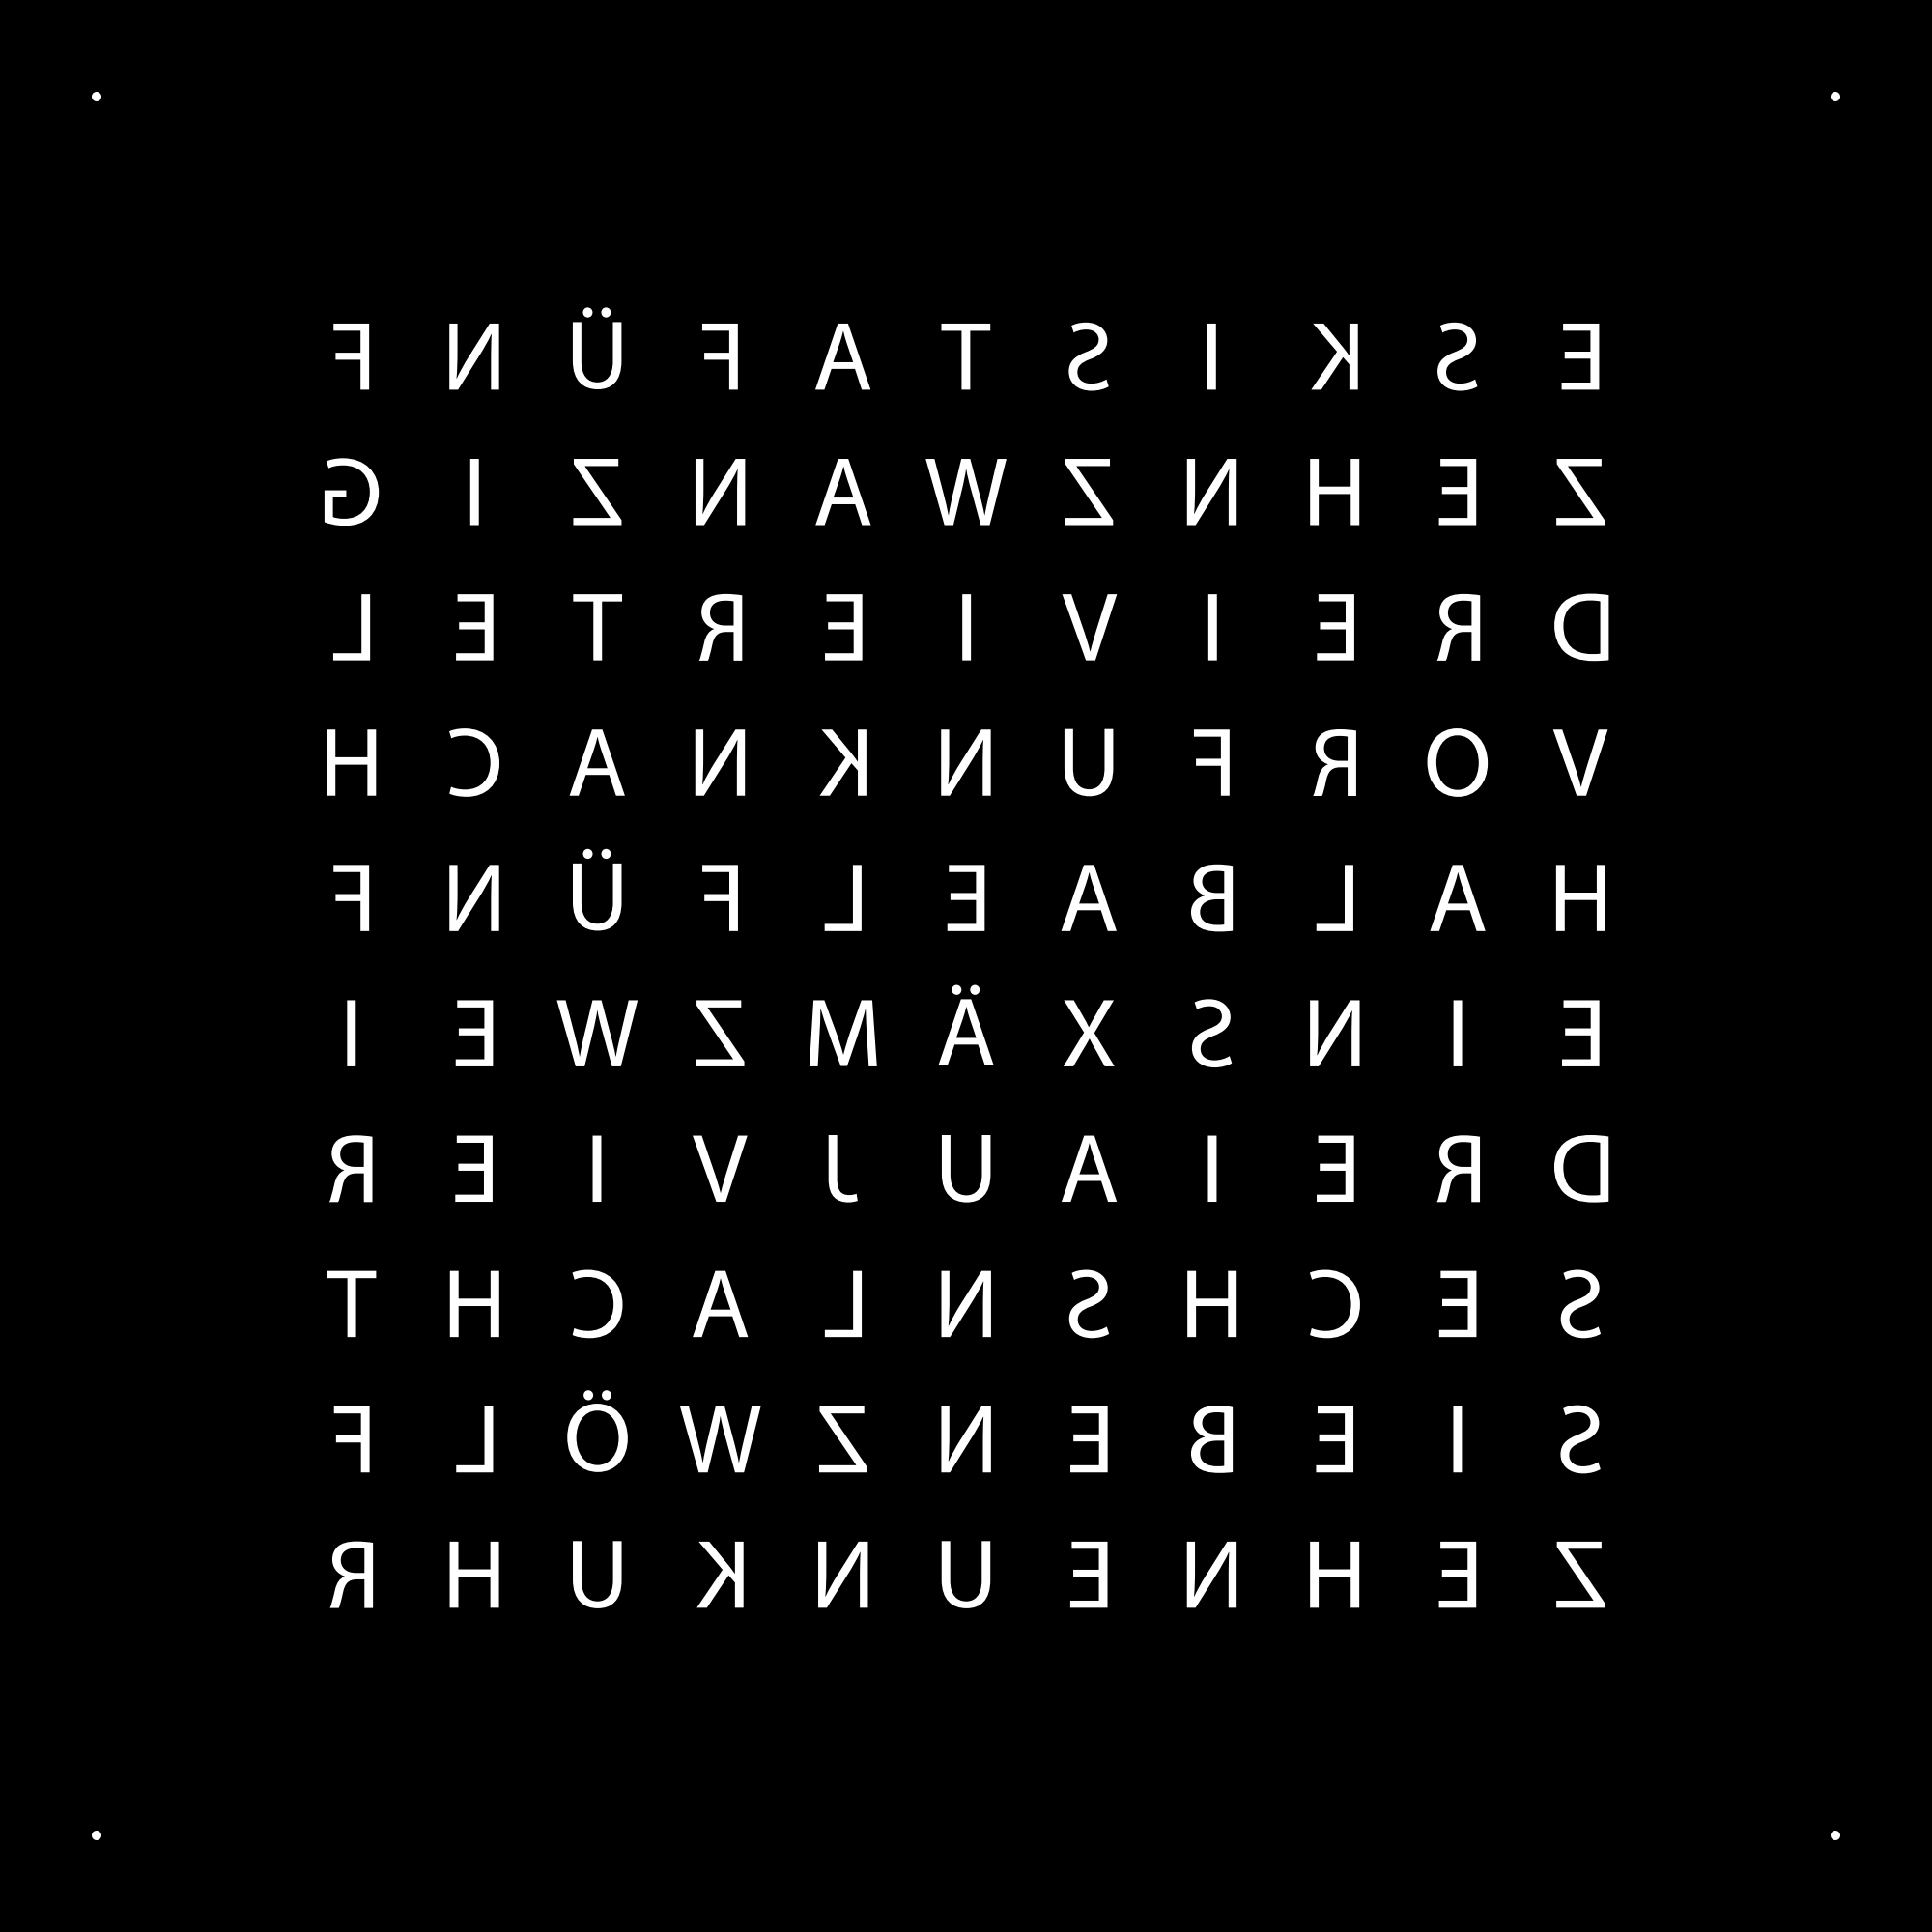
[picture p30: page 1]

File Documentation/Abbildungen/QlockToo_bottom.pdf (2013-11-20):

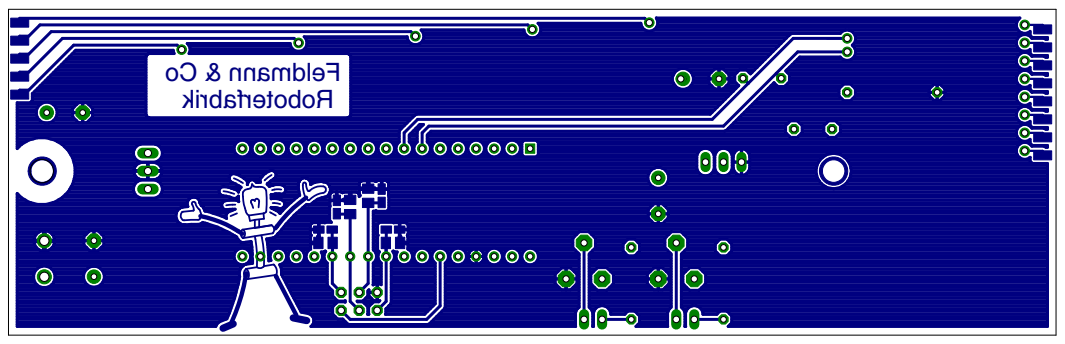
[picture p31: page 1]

oC & nna mdl eF

kir bafr et oboR

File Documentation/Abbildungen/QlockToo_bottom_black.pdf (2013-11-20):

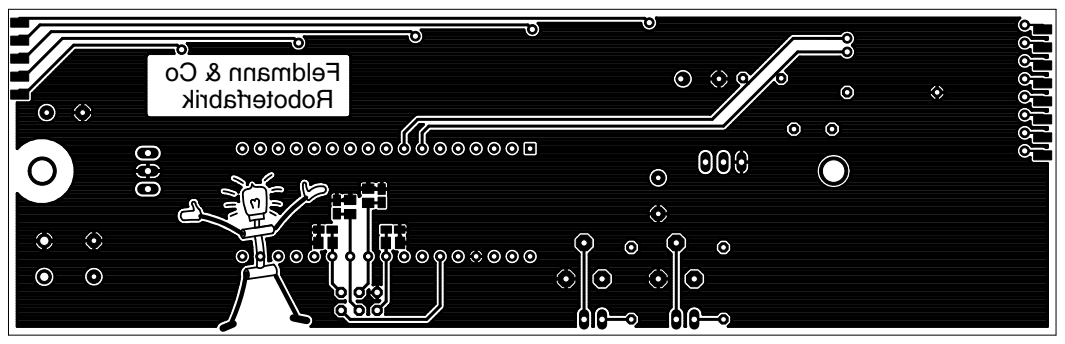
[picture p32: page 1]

oC & nna mdl eF

kir bafr et oboR

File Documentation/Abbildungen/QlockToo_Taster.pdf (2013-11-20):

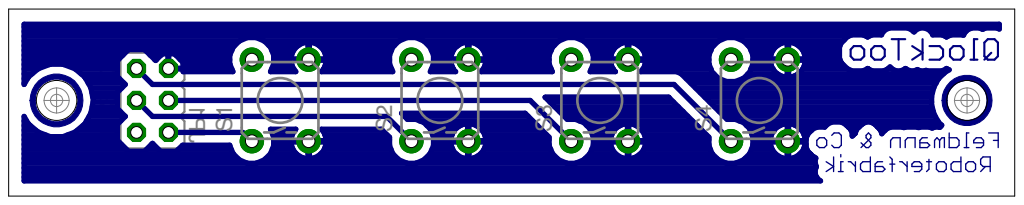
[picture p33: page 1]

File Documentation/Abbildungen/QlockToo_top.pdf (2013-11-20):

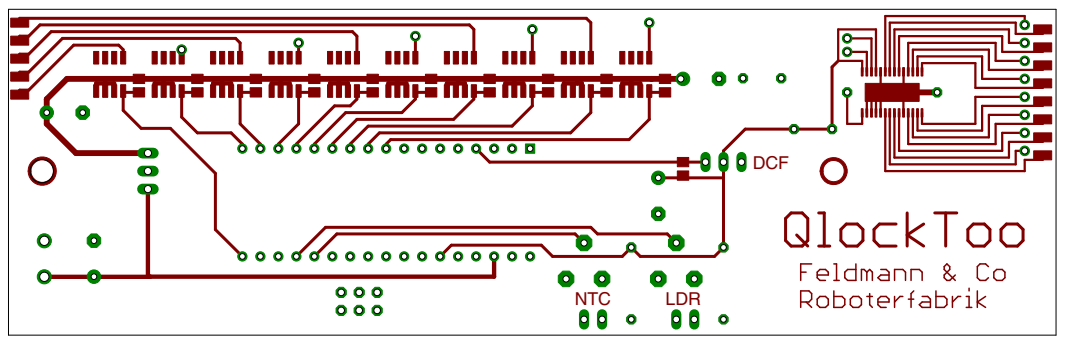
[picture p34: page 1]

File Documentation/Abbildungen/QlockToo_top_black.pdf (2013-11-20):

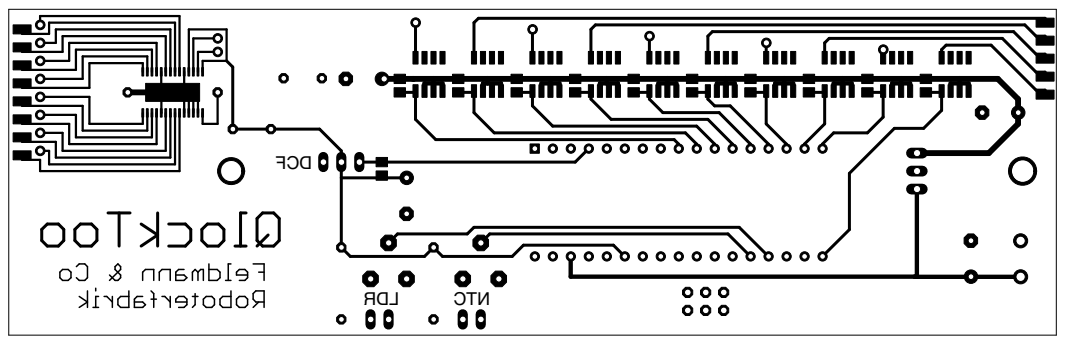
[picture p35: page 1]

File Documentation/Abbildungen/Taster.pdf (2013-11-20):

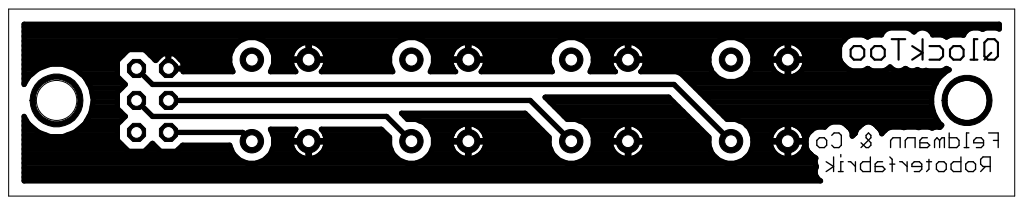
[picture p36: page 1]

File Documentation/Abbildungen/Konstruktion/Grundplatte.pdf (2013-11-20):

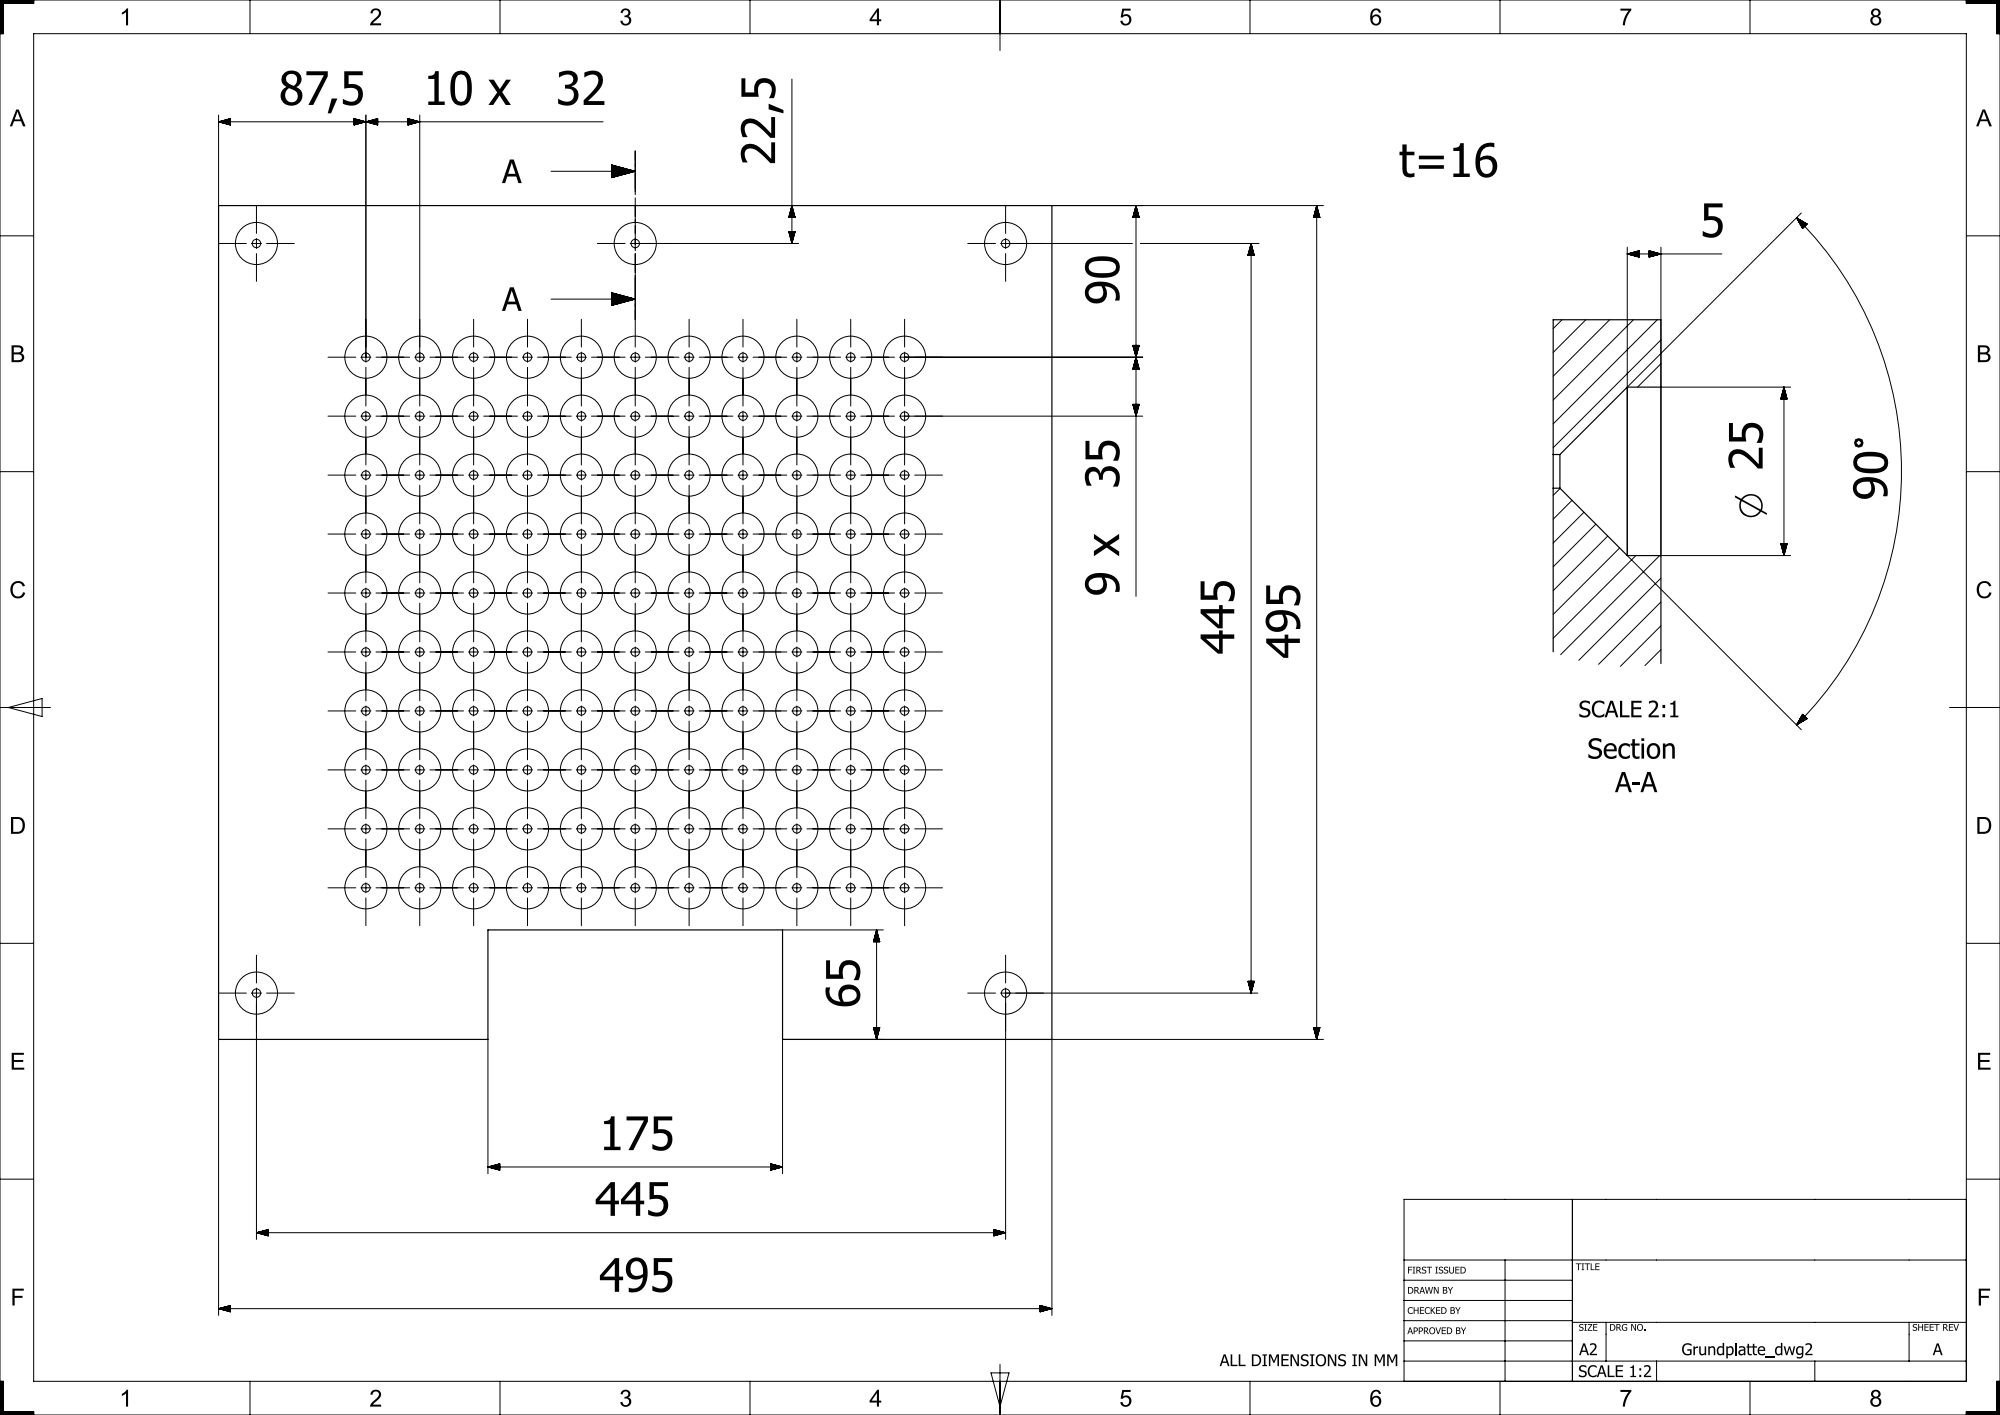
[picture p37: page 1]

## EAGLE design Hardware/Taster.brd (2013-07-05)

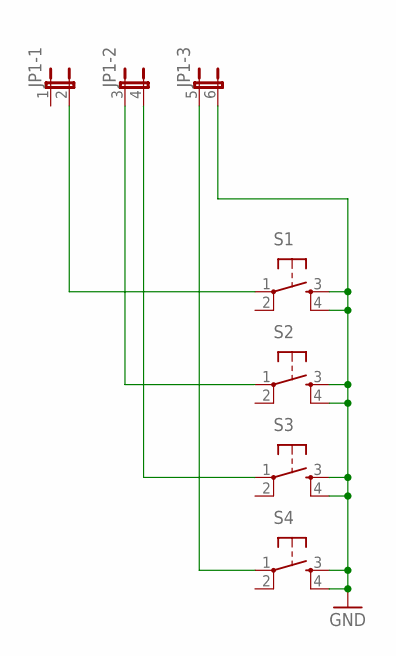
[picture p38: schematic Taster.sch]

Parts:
JP1: JP3QE; JP3Q
S1, S2, S3, S4: TAC_SWITCHPTH; TACTILE-PTH

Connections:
GND: JP1.6 (2), S1.3, S1.4, S2.3, S2.4, S3.3, S3.4, S4.3, S4.4
unnamed: JP1.2, S1.1
unnamed: JP1.3 (1), S2.1
unnamed: JP1.4 (2), S3.1
unnamed: JP1.5 (1), S4.1

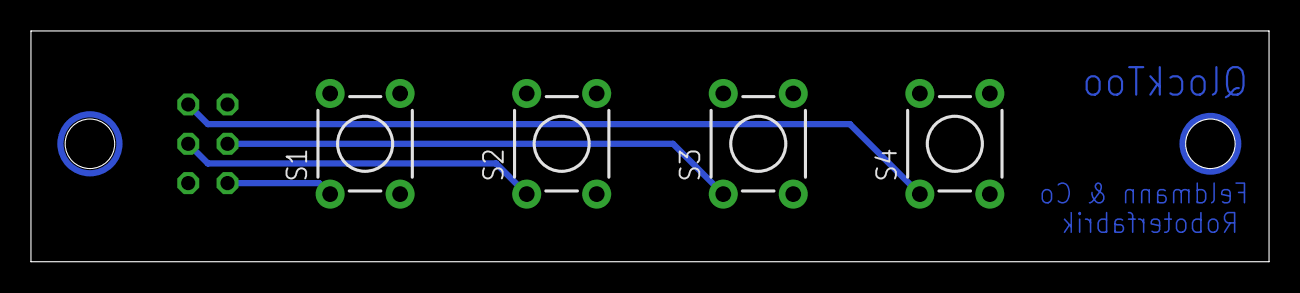
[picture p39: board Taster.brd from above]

Board: 2 copper layers, 80.0 x 14.9 mm, 5 parts (1 on the bottom side), 5 nets.

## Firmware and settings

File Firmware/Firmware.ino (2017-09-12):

/*     ____    __           __  ______
 *    / __ \  / /___  _____/ /_/_  __/___  ____
 *   / / / / / / __ \/ ___/ //_// / / __ \/ __ \
 *  / /_/ / / / /_/ / /__/ ,<  / / / /_/ / /_/ /
 *  \___\_\/_/\____/\___/_/|_|/_/  \____/\____/
 *
 *  Firmware entry point for the QlockToo, an open-source remake of the QlockTwo
 *  Author: Thomas Feldmann
 *
 *  Timer1:    1/s   keeps track of the time
 *  Timer3: 1000/s   main timer for display / api / controller
 */
#include <TimerThree.h>
#include "globals.h"

#define VERSION "1.2"

void setup()
{
    Serial.begin(115200);

    // initialize components
    api_init();
    time_init();
    display_init();
    controller_init();

    // start main timer
    Timer3.initialize(1000); // 1e6 / 1000 = 1kHz in µs
    Timer3.attachInterrupt(main_timer);
}

void main_timer()
{
    // update display
    display_update();

    // update controller every 10ms
    static uint8_t ms = 0;
    if (++ms == 10)
    {
        controller_update();
        ms = 0;
    }
}

void loop()
{
    api_update();
}

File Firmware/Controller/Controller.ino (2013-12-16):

//
// Controller.ino
//

#include "globals.h"

// the time module will care for setting this flag, just make sure to reset
// it after you read it.
extern volatile bool second_has_changed, minute_has_changed, hour_has_changed;
extern volatile bool brightness_has_changed;
#define BUTTON_PRESSED(_x_) (!last_status[_x_] && status[_x_])


void controller_init()
{
    STATE_MACHINE_START(STATE_TIMEWORDS);
}


void controller_update()
{
    controller_statemachine();

    // reset the second / minute / hour has_updated flags
    time_resetFlags();

    controller_buttons();
}


void controller_buttons()
{
    // variable declarations
    const int button[] = {A5, A4, A3, A2};
    static bool last_status[] = {false, false, false, false};

    // read in current button status
    bool status[4];
    for (byte i = 0; i < 4; i++)
    {
        status[i] = digitalRead(button[i]);
    }

    if (BUTTON_PRESSED(0))
    {
        STATE_SWITCH(STATE_TIMEWORDS);
    }
    if (BUTTON_PRESSED(1))
    {
        STATE_SWITCH(STATE_SECONDS);
    }
    if (BUTTON_PRESSED(2))
    {
        STATE_SWITCH(STATE_TEMPERATURE);
    }
    if (BUTTON_PRESSED(3))
    {
        brightness_next_step();
    }
    if (BUTTON_PRESSED(0) && BUTTON_PRESSED(1))
    {
        STATE_SWITCH(STATE_ES_LACHT_NE_KUH);
    }

    // copy status to last status
    for (byte i = 0; i < 4; i++)
    {
        last_status[i] = status[i];
    }
}


void controller_statemachine()
{
STATEMACHINE

    STATE_ENTER(STATE_TIMEWORDS)
        #ifdef DEBUG
            Serial.println("#State: Timewords");
        #endif
        timewords_show();
    STATE_LOOP
        brightness_update();
        if (minute_has_changed)
        {
            timewords_show();
        }
    STATE_LEAVE
    END_OF_STATE

    STATE_ENTER(STATE_SECONDS)
        #ifdef DEBUG
            Serial.println("#State: Seconds");
        #endif
        matrix_second(seconds);
    STATE_LOOP
        brightness_update();
        if (second_has_changed)
        {
            matrix_second(seconds);
        }
    STATE_LEAVE
    END_OF_STATE

    STATE_ENTER(STATE_TEMPERATURE)
        #ifdef DEBUG
            Serial.println("#State: Temperature");
        #endif
    STATE_LOOP
        brightness_update();
        float temp = thermo_celsius();
        thermo_display((int)temp);
    STATE_LEAVE
    END_OF_STATE

    STATE_ENTER(STATE_ES_LACHT_NE_KUH)
        matrix_clear();
        matrix[0][0]  = 1;
        matrix[0][1]  = 1;
        matrix[7][6]  = 1;
        matrix[7][7]  = 1;
        matrix[7][8]  = 1;
        matrix[7][9]  = 1;
        matrix[7][10] = 1;
        matrix[9][3]  = 1;
        matrix[9][4]  = 1;
        matrix[9][7]  = 1;
        matrix[9][8]  = 1;
        matrix[9][9]  = 1;
    STATE_LOOP
        brightness_update();
    STATE_LEAVE
    END_OF_STATE

    STATE_ENTER(STATE_STREAM)
        #ifdef DEBUG
            Serial.println("#State: Stream");
        #endif
    STATE_LOOP
        brightness = 1;
        // global brightness must be 1 because the pc already
        // sends brightness values from 0-255
    STATE_LEAVE
    END_OF_STATE

END_STATEMACHINE
}

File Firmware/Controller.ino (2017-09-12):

//
// Controller.ino
//

#include <Bounce.h>
#include "globals.h"

// Buttons
Bounce btn1 = Bounce(A5, 5);
Bounce btn2 = Bounce(A4, 5);
Bounce btn3 = Bounce(A3, 5);
Bounce btn4 = Bounce(A2, 5);

// the time module will care for setting this flag, just make sure to reset
// it after you read it.
extern volatile bool second_has_changed, minute_has_changed, hour_has_changed;
extern volatile bool brightness_has_changed;


void controller_init()
{
    STATE_MACHINE_START(STATE_TIMEWORDS);
}


void controller_update()
{
    brightness_update();
    controller_statemachine();
    time_resetFlags();  // reset the second / minute / hour has_updated flags
    controller_buttons();
}


void controller_buttons()
{
    btn1.update();
    btn2.update();
    btn3.update();
    btn4.update();

    if (btn1.risingEdge())
    {
        STATE_SWITCH(STATE_TIMEWORDS);
    }
    if (btn2.risingEdge())
    {
        STATE_SWITCH(STATE_SECONDS);
    }
    if (btn3.risingEdge())
    {
        STATE_SWITCH(STATE_TEMPERATURE);
    }
    if (btn4.risingEdge())
    {
        brightness_next_step();
    }

    // cycle through demo modes
    if (btn1.read() && btn2.risingEdge())
    {
        if (STATE_IS_ACTIVE(STATE_TIMEWORDS))
            STATE_SWITCH(STATE_WHITE);

        if (STATE_IS_ACTIVE(STATE_WHITE))
            STATE_SWITCH(STATE_GRADIENT);

        if (STATE_IS_ACTIVE(STATE_GRADIENT))
            STATE_SWITCH(STATE_FADE);

        if (STATE_IS_ACTIVE(STATE_FADE))
            STATE_SWITCH(STATE_MATRIX);

        if (STATE_IS_ACTIVE(STATE_MATRIX))
            STATE_SWITCH(STATE_ES_LACHT_NE_KUH);

        if (STATE_IS_ACTIVE(STATE_ES_LACHT_NE_KUH))
            STATE_SWITCH(STATE_TIMEWORDS);
    }

    // switch to automatic brightness mode
    if (btn4.read() && btn4.duration() > 1000)
    {
        brightness_enable_automatic();
    }

    // wait for dcf signal
    if (btn1.read() && btn1.duration() > 1000 &&
        btn2.read() && btn2.duration() > 1000 &&
        btn3.read() && btn3.duration() > 1000)
    {
        STATE_SWITCH(STATE_WAIT_FOR_DCF);
    }
}


void controller_statemachine()
{
STATEMACHINE

    STATE_ENTER(STATE_TIMEWORDS)
        #ifdef DEBUG
            Serial.println("#State: Timewords");
        #endif
        timewords_setup();
    STATE_LOOP
        timewords_loop();
    STATE_LEAVE
    END_OF_STATE

    STATE_ENTER(STATE_SECONDS)
        #ifdef DEBUG
            Serial.println("#State: Seconds");
        #endif
        seconds_setup();
    STATE_LOOP
        seconds_loop();
    STATE_LEAVE
    END_OF_STATE

    STATE_ENTER(STATE_TEMPERATURE)
        #ifdef DEBUG
            Serial.println("#State: Temperature");
        #endif
        temperature_setup();
    STATE_LOOP
        temperature_loop();
    STATE_LEAVE
    END_OF_STATE

    STATE_ENTER(STATE_WAIT_FOR_DCF)
        #ifdef DEBUG
            Serial.println("#State: Waiting for DCF Signal");
        #endif
        display_clear();
        corner_clear();
        matrix[3][3] = BRIGHTNESS_FULL;  // F
        matrix[3][4] = BRIGHTNESS_FULL;  // U
        matrix[3][5] = BRIGHTNESS_FULL;  // N
        matrix[3][6] = BRIGHTNESS_FULL;  // K
    STATE_LOOP
    STATE_LEAVE
    END_OF_STATE

    STATE_ENTER(STATE_WHITE)
        display_fill(BRIGHTNESS_FULL);
        corner_fill(BRIGHTNESS_FULL);
    STATE_LOOP
    STATE_LEAVE
    END_OF_STATE

    STATE_ENTER(STATE_GRADIENT)
        display_clear();
        corner_clear();
        for (int row = 0; row < ROWS; row++) {
            for (int col = 0; col < COLS; col++) {
                matrix[row][col] = 255 - 255 * (row / (float)ROWS);
            }
        }
    STATE_LOOP
    STATE_LEAVE
    END_OF_STATE

    STATE_ENTER(STATE_FADE)
        demo_fade_setup();
    STATE_LOOP
        demo_fade_loop();
    STATE_LEAVE
    END_OF_STATE

    STATE_ENTER(STATE_MATRIX)
        demo_matrix_setup();
    STATE_LOOP
        demo_matrix_loop();
    STATE_LEAVE
    END_OF_STATE

    STATE_ENTER(STATE_ES_LACHT_NE_KUH)
        display_clear();
        corner_clear();
        matrix[0][0]  = BRIGHTNESS_FULL;  // E
        matrix[0][1]  = BRIGHTNESS_FULL;  // S
        matrix[7][6]  = BRIGHTNESS_FULL;  // L
        matrix[7][7]  = BRIGHTNESS_FULL;  // A
        matrix[7][8]  = BRIGHTNESS_FULL;  // C
        matrix[7][9]  = BRIGHTNESS_FULL;  // H
        matrix[7][10] = BRIGHTNESS_FULL;  // T
        matrix[9][3]  = BRIGHTNESS_FULL;  // N
        matrix[9][4]  = BRIGHTNESS_FULL;  // E
        matrix[9][7]  = BRIGHTNESS_FULL;  // K
        matrix[9][8]  = BRIGHTNESS_FULL;  // U
        matrix[9][9]  = BRIGHTNESS_FULL;  // H
    STATE_LOOP
    STATE_LEAVE
    END_OF_STATE

END_STATEMACHINE
}

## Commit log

2013-03-21 removed connect button in favor of a select list
2013-04-09 removed update button
2013-04-09 added a device class
2013-04-14 added device display properties
2013-04-22 Added LedBar Testcode
2013-05-09 removed serial calls in interrupts
2013-05-09 removed timer from display module
2013-07-05 added qlocktoo schematics
    [QlockToo.brd, QlockToo.sch]
2013-07-05 added button board schematics
    [Taster.brd, Taster.sch]
2013-07-09 added corner case
2013-10-14 added timer
2013-10-14 dump time in main loop, not in interrupt
2013-10-14 added api for switching states
2013-10-16 added function prototype for matrix_timewords
2013-10-26 removed file leddriver
2013-10-26 added alternative I2C library
2013-10-28 added Button tab
2013-10-28 added button file
2013-10-28 reformating and button handling
2013-10-28 added a filter for the brightness values
2013-10-28 formatting modifications to brightness filter
2013-10-29 filter adjustment
2013-11-06 moved button updated to loop, state machine updates to display
2013-11-15 simplified brightness filter
2013-11-15 connected the dcf77 to a different pin
2013-11-20 Inhalt und Platzhalter für Grafiken
2013-11-20 Arduino pic
2013-11-20 added ground plate drawing
2013-12-04 better device management
2013-12-04 added device connection
2013-12-04 Korrektur - nach Möglichkeit vermeiden der Umgangssprache
2013-12-11 deleted button page
2013-12-11 added buttons to controller
2013-12-13 Bilder und Konstruktion
2013-12-13 fixed dcf77 pin
2013-12-13 print clock protocol data
2013-12-16 Konstruktion und Produktion -.-
2013-12-16 Korrekturen und Umbenennung Unterkapitel
2013-12-16 Kapitel Funkionen - zur Erklärung der Taster :)
2013-12-18 Änderung der Struktur - möglichst einfach - zu viele Unterkapitel "ohne" Inhalt gefallen mir nicht
2013-12-19 Wer spielt denn hier an der Firmware rum!
2013-12-19 added state switch to dcf77
2013-12-19 display driver enhancements
2013-12-19 use of interrupts(); and noInterrupts()
2013-12-19 better formatting for display driver
2013-12-20 just the first three buttons for waiting state
2013-12-20 interrupt handling
2013-12-20 timer bugfix!
2013-12-20 added rudimentary matrix prototype
2014-01-06 Formatierung der Einleitung
2014-01-06 Software und Firmware
2014-01-06 Formatierung und Grafiken
2014-01-06 Konstruktion und Elektronik getauscht
2014-01-06 Sekunden und Temperatur
2014-03-22 changes to device communication
2014-03-22 separated device and simulator

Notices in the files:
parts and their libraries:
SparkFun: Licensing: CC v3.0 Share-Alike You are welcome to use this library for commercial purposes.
